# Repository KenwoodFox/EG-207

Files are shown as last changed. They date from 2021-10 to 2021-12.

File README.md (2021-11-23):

EG-207
======








Feel free to fork or create your own PRs! Join us on our [discord](https://discord.gg/vbgyRJBJCs)!

## Getting started building this code

More to come <3

### Tag Naming Scheme

Assignments should stay off this repo.  
Labs should use tags like so:  
`L<lab number>-RC<revision>`  
Labs should also not use subrevisions, and should rely on their `describe` functions to count appendex commits.

The final project should use:
`CMS-0.0`  
or  
`CMS-0.0RC0`

For example:
```
L1-RC1
L1-RC2
L1-RC3
```

And for final project
```
CMS-0.1RC1
CMS-0.1
CMS-0.2
CMS-0.3
CMS-0.4RC1
CMS-0.4RC2
```

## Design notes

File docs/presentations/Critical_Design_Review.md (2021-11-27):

---
title:
 - Team Gold Critical Design Review
subtitle:
 - Version &hash
author:
 - Joe
 - Maria
 - Noah
 - Josh
 - William
institute:
 - SNHU/CETA, EG-207
titlegraphic: resources/SNHU-CETA.png
theme: Ilmenau
navigation: frame
date: "Build Date: &date"
aspectratio: 1610
logo: resources/logo.png
fontsize: 8pt
section-titles: false
toc: false
---

# Introduction

## CDR Agenda

 - Concept of Operations (ConOps) Summary
 - Environmental Systems Description
 - Environmental Sensors
 - Requirement Compliance
 - Front Panel Display, Base-plate and Housing Design Details
 - Summary of Analyses
 - Calibration Plan
 - References/Citations
 - Next Steps

## Concept of Operations (ConOps) Summary

 - Stakeholders
   - We hold some stake in our own system.
   - The completion of our lab is important to those grading it.
 - Users
   - Scientists and Analysts in the field.
 - Operational Description
   - The sensor should be operated indoors and may be left without supervision to collect data and store it.
 - Support Environment
   - Released under the [GNUv3](https://www.gnu.org/licenses/gpl-3.0.en.html) license after final graded release `CMS-1.0-RELEASE` is published, and supported as the license describes, extending absolutely no warranty, and making all source code fully open source.

## Concept of Operations (ConOps) Summary Cont.

 - Use
   - The operator/analyst will use the sensor in the field, and collect data supervised or not.
 - Calibration
   - Calibration data is stored in the EEPROM and the sensor will not require calibration between regular uses, the sensor is not expected to require calibration often but will have a procedure to do so.
 - Impact consideration
   - Because our environmental monitoring solution does not have the same level of quality assurance as a similar solution, over-reliance by the end user could result in uncalibrated data, unexpected failure modes or strange untested bugs over time.
 - Risks
   - Increased risk of the system to malfunction if operation of system is prolonged without proper maintenance.
   - Potential light scatter non-visible to the naked eye.
   - Airborne contaminants can cause the system to malfunction and provide inaccurate data.

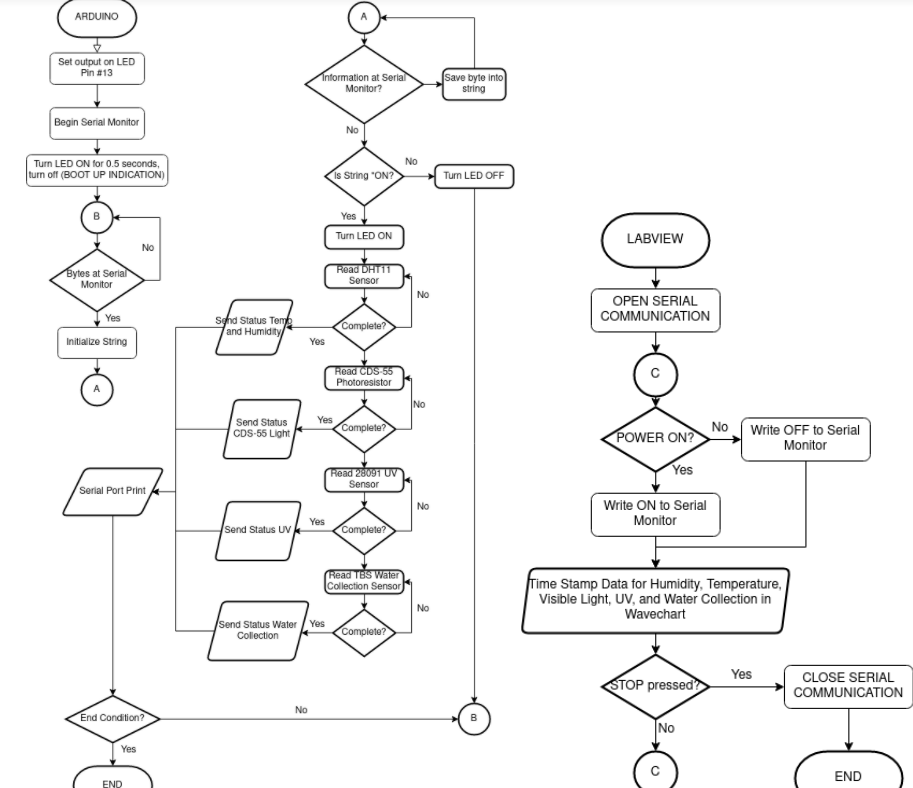
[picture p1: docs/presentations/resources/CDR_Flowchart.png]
Flowchart


## Environmental System Description

::: columns

:::: column

### Functional Block Diagram

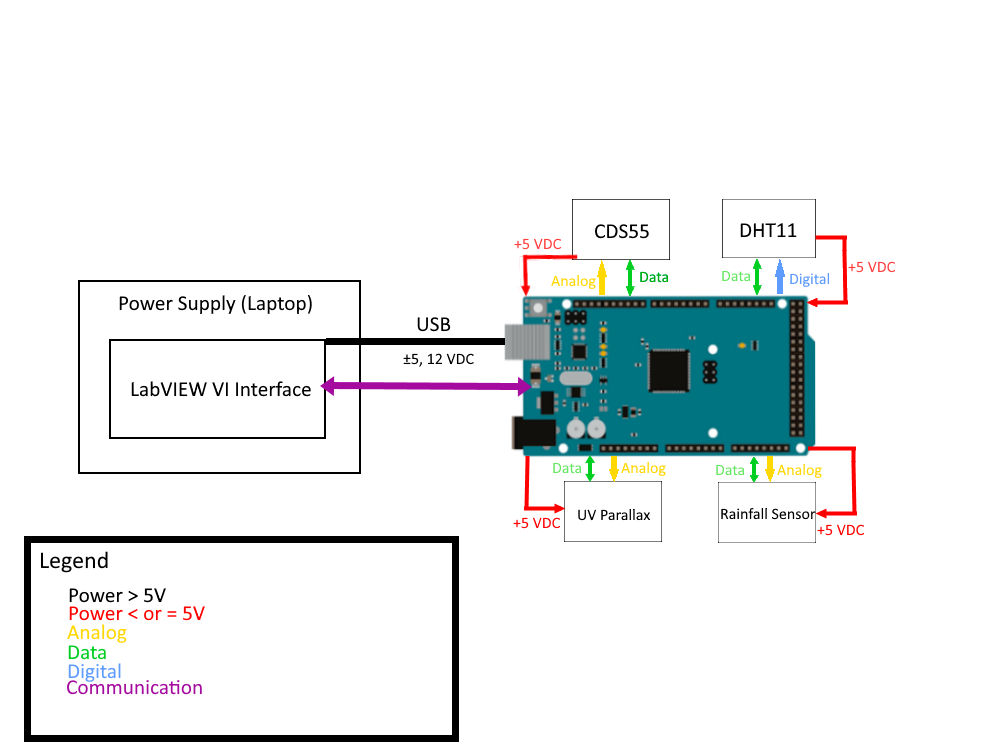
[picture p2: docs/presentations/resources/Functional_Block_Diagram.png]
Functional Block Diagram


::::

:::: column

- Instrument: LabVIEW 2019 SP1
- Data Acquisition: Arduino Mega 2560
- DAC Software: Arduino IDE 1.8.15
- Sensors:
  - Temp/RH: DHT11 Sensor
  - Visible Light: CDS55 Photoresistor
  - UV Light: 28091 UV Parallax Sensor
  - Water Collection: DGZZI Water Level Sensor Module

::::

:::

::: notes

This page needs some more work.

:::

## Environmental Sensors & Interfaces

::: columns

:::: {.column width=25%}

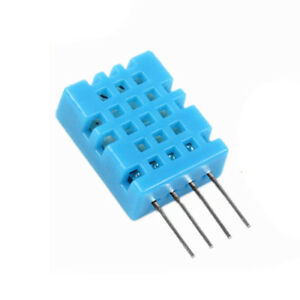
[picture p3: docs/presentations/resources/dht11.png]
DHT 11


The DHT 11 is an inexpensive  
serial type thermometer and  
hydrometer (John).

 - Humidity
   - Accuracy: ±5% RH
   - Precision: ±2% 
   - Response Time: 30 seconds

 - Temperature
   - Accuracy: ±2.5%
   - Precision: 2 Degrees Celcius 
   - Response Time: 30 seconds

::::

:::: {.column width=25%}

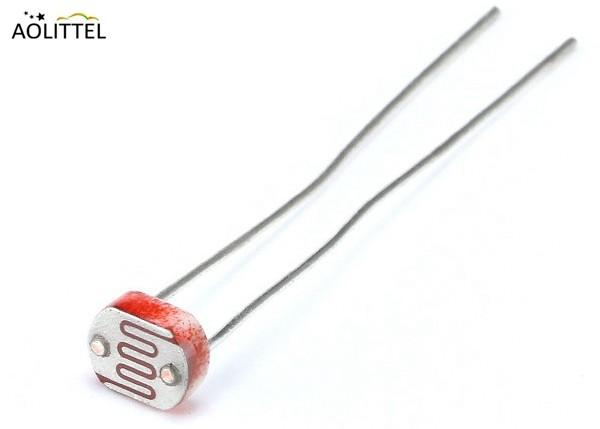
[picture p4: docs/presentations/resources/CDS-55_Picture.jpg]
CDS 55 Photoresistor


The CDS 55 is a commonly used  
visible light detecting photoresistor (KlSelectronic).

   - Accuracy: 10%
   - Precision: 20 lux 
   - Response Time: 0.30 seconds

::::

:::: {.column width=25%}

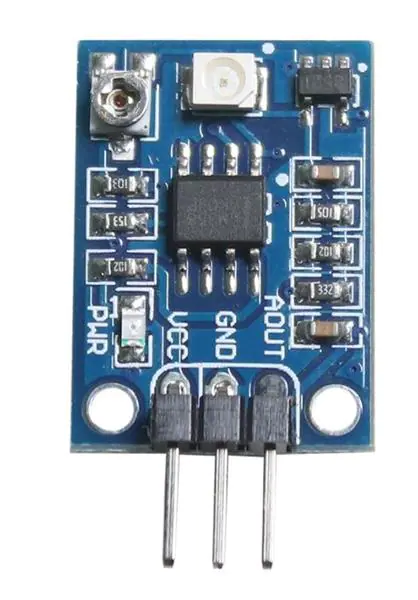
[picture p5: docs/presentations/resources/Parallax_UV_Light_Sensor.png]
Parallax UV Light Sensor


The parallax UV Sensor Breakout  
board is a breakout board  
used in prototypes  
to sense UV Light ("UV Light Sensor").

   - Accuracy: N/A
   - Precision: N/A 
   - Response Time: N/A

::::

:::: {.column width=25%}

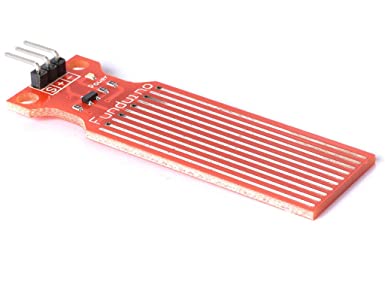
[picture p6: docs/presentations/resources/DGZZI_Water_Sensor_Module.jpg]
Water Level Sensor


The Water Level Sensor is used to 
measure the depths of water and the 
core component in an amplifying circuit.
The brick-designed sensor has three major
components: electronic brick connector,
1Mohm resistor, and several lines of
bare-conducting wires ("Last Minute Engineers"). 

   - Accuracy: ±1 mm
   - Precision: 0.2 mm 
   - Response Time: TBD

::::

:::

::: notes

This page needs some more work.

:::

# Requirements

## Functional Requirements - Compliance

| Reqt | Reqt Title | Statement Subject | Reqt Value | Perf.  | Margin | Notes/Basis |
|---|---|---|---|---|---|---|
| 3.1.1 | VI Front Panel | | | Comply | | |
| 3.1.1.1 | Sensor Read and Indications  | Numeric Indicators, "Warning" and "Alarm" LEDs | Provide for all sensors | Comply | N/A | Physical Indicators as well. |
| 3.1.1.2 | Senors Controls | Provide necessary controls | Arduino Power and STOP  | Comply | N/A | |
| 3.1.1.3 | Operation Indications | Display current system configuration and operating mode | LEDs for Indication | Comply | N/A | Physical Indicators as well. |
| 3.1.1.4 | Calibration Updates | Update Calibration Parameters through LabVIEW | | Comply | | |
| 3.1.2 | Update/Read Rate | | | | | |
| 3.1.3 | Warning and Alarm Indication | Provide warning or alarm indication for each sensor | | | | |

## Functional Requirements - Compliance Cont.

| Reqt | Reqt Title | Statement Subject | Reqt Value | Perf.  | Margin | Notes/Basis |
|---|---|---|---|---|---|---|
| 3.1.3.1 | Temperature (°F)  | Provide temperature warning or alarm indication | 85<T<100, > 100 | Comply | ±2^-1^ | |
| 3.1.3.2 | Humidity | Provide humidity warning or alarm indication | 30%<RH<40%, < 30% | Comply | | |
| 3.1.3.3 | Visible Light(lux)| Provide lux warning or alarm indication | 700<lux<1000, > 1000  | Comply | | |
| 3.1.3.4 | UV Light | Provide UV intensity warning or alarm indication | 300<U<600, > 600 | Comply | | |
| 3.1.3.5 | Water Level (mm)  | Provide rainfall warning or alarm indication | W<0.5 or 6<W<10, > 10 | Comply | | |
| 3.1.4 | Waveform Display  | Display waveform for sensors | Demonstrate | Comply | | |
| 3.1.5 | Data Logging | Time-stamped data exported to file with specific filename | Demonstrate, Inspect  | Comply | | On-Microcontroller Timestamp (to negate serial delay) |
| 3.1.6 | Operational Mode  | Provide additional mode | Demonstrate | Comply | | |

## Performance Requirements - Compliance

| Reqt. ID or section | Reqt. Title | Statement Subject | Reqt. Value | Perf. | Margin | Notes/Basis |
|---|---|---|---|---|---|---|
| 3.2.1 | Accuracy | Accuracy better than; | --- | | | |
| --- | --- | Temperature | ± 2.5ºC | ± 1.35ºC| 46.00% | |
| --- | --- | Humidity | ± 7% | ± 5.84% | 16.57% | |
| --- | --- | Vis Illuminance | ± 10% | ± 8.21% | 17.90% | |
| --- | --- | UV Intensity | N/A | N/A | N/A | N/A |
| --- | --- | Range detection | ± 1 mm | TBD | TBD | TBD |
| 3.2.2 | Precision | Precision better than; | --- | | | |
| --- | --- | Temperature | 2ºC | 1.23ºC  | 38.50% | |
| --- | --- | Humidity | 2% | 2.69% | -34.50%| |
| --- | --- | Vis Illuminance | 20 Lux | 2.69 | 86.55% | |
| --- | --- | UV intensity | N/A | N/A | N/A | N/A |
| --- | --- | Range detection | 0.2 mm | TBD | TBD | TBD |
| 3.2.3 | Calibration or Diagnostics | The display Shall provide ability to update calribration | Update via numerical Controls | Comply  | | |

# Prototypes

## Front Panel Display Design (LabVIEW)

::: columns

:::: {.column width=60%}

### LabView Front Panel

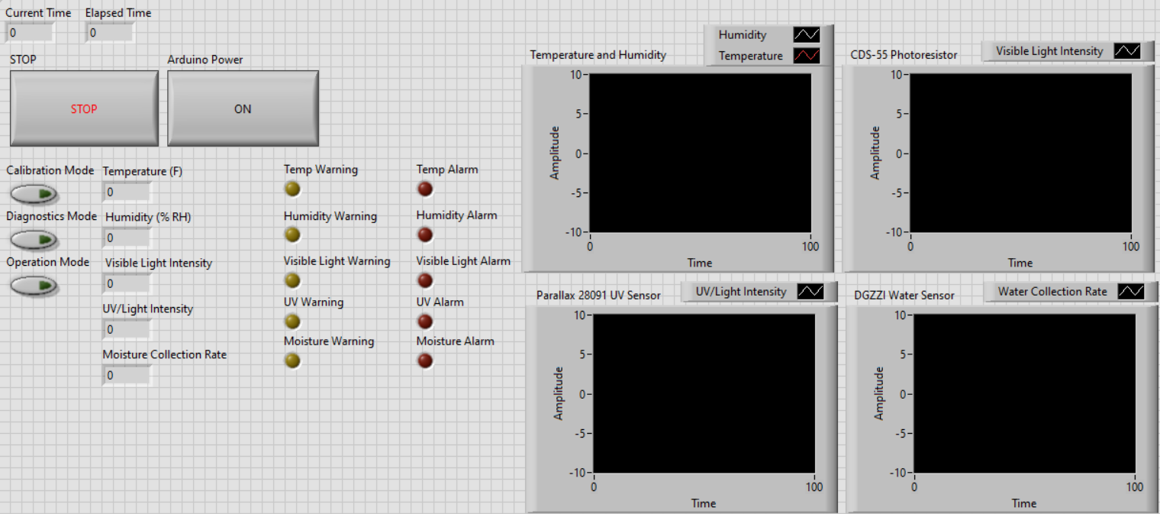
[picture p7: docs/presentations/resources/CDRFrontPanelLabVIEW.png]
Team Gold LabView Front Panel


::::

:::: column

- Environmental Varaiables
  - Temperature
  - Humidity
  - Visible Light Intensity
  - UV/Light Intesnsity
  - Moisture Collection Rate

- Control Functions
  - On & Off switch for LabVIEW
  - Calibration Mode
  - Diagnostics Mode
  - Operation Mode

- Sensor Warning Lights
  - Temperature Warning light
  - Humidity Warning light
  - Visible Light Warning light
  - UV/Light Warning light
  - Moisture Warning light

- Sensor Alarm Light 
  - Temperature Alarm light
  - Humidity Alarm light
  - Visible Light Alarm light
  - UV/Light Alarm light
  - Moisture Alarm light

::::

:::

::: notes

This page needs some more work.

:::

## Sensor Package Assembly Model

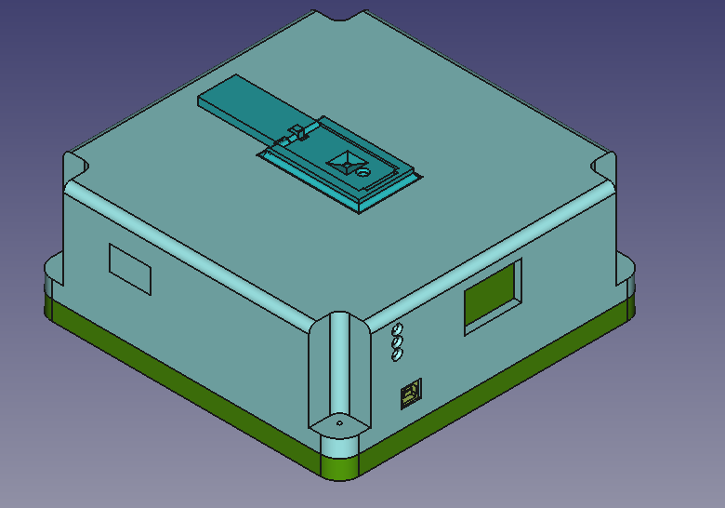
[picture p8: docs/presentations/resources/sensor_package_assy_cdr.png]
Team Gold Sensor Package Assembly Model


::: notes

This page needs some more work.

:::

## Base plate Design Drawing

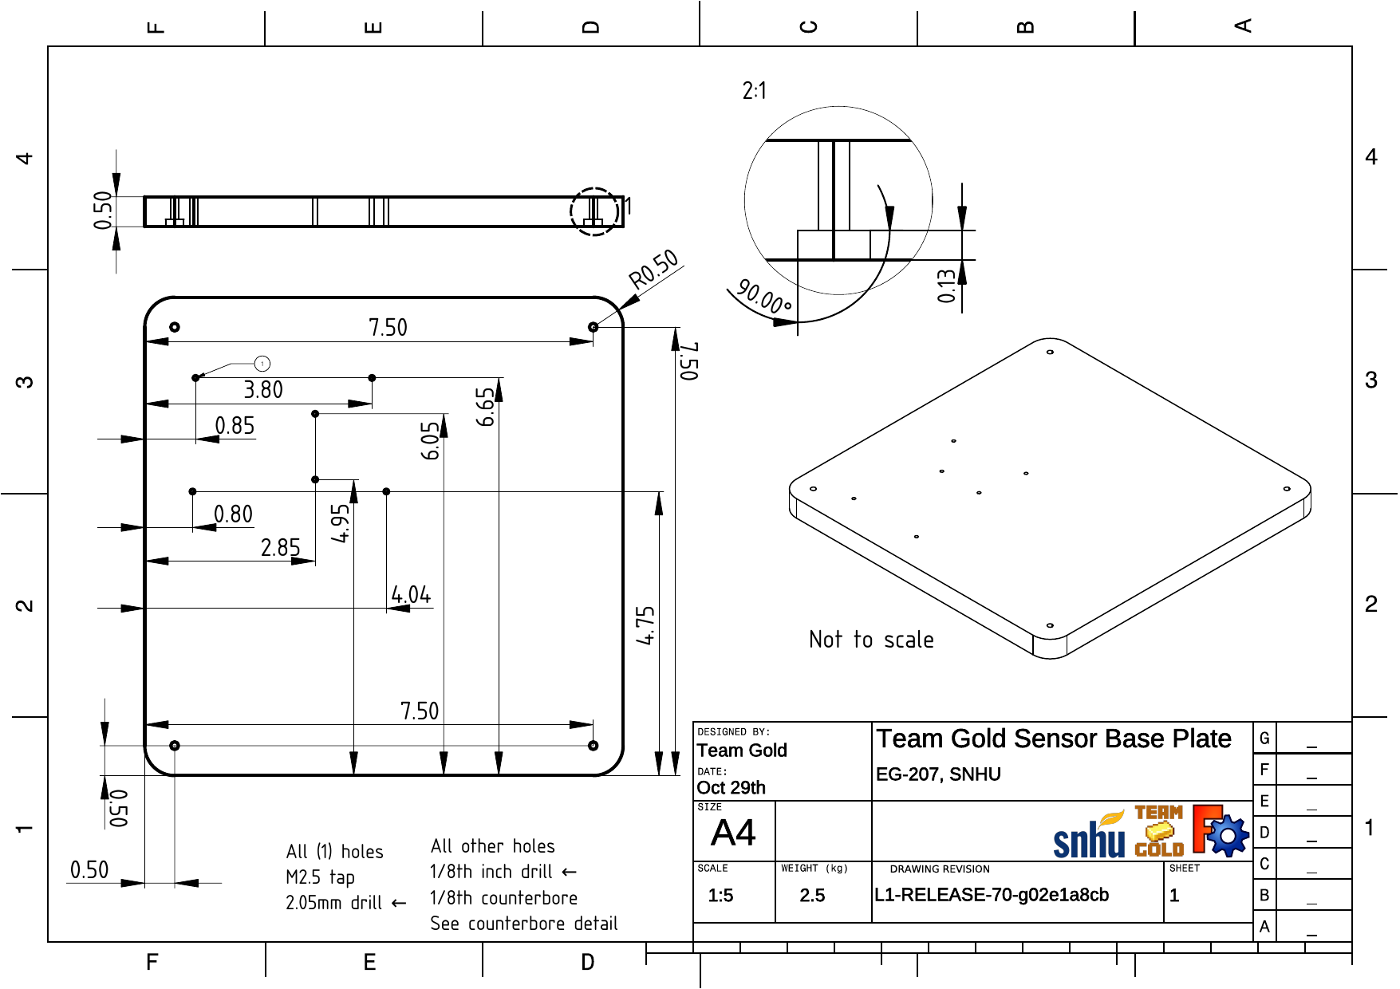
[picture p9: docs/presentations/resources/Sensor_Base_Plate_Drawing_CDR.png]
Team Gold Base Plate Design


::: notes

This page needs some more work.

:::

## Housing Design - Solid Model

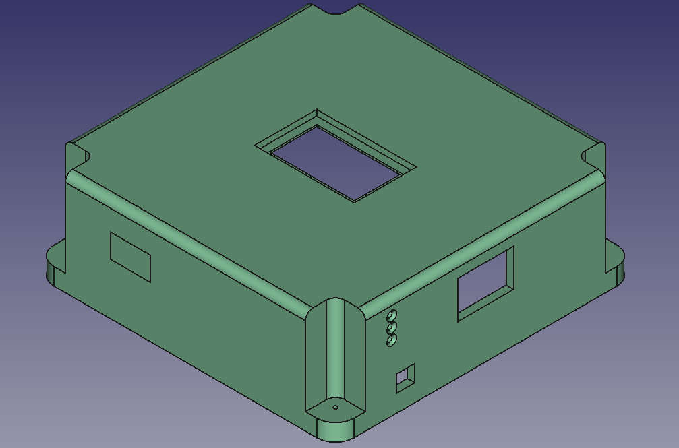
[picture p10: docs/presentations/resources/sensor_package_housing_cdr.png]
Team Gold Solid Model


::: notes

Have some callouts and stuff for  
important features and cutouts on model.

:::

## Housing Design - Drawing

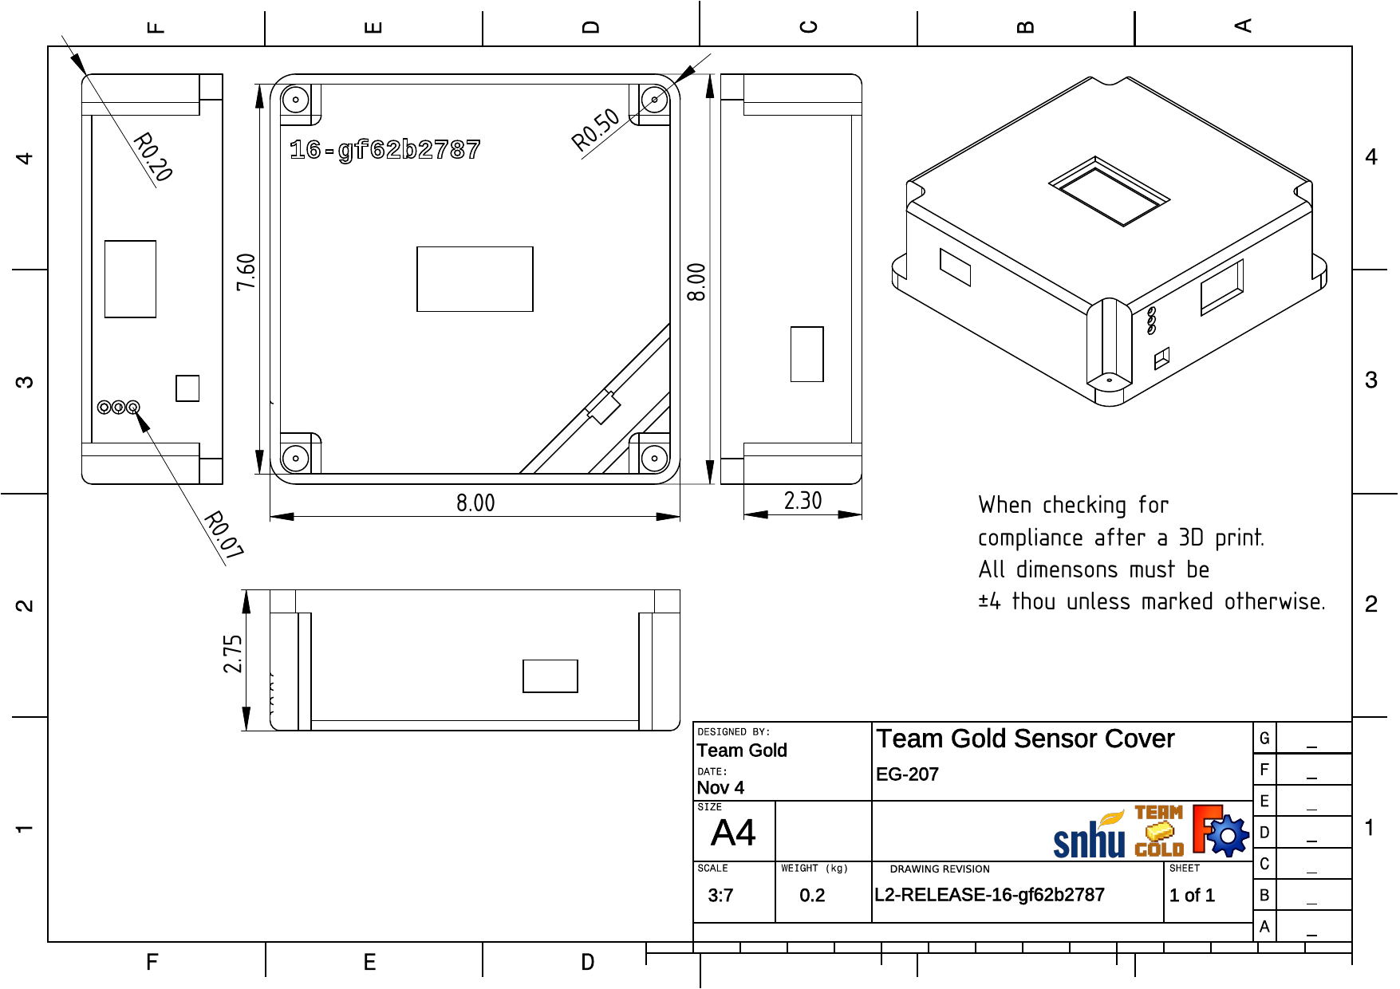
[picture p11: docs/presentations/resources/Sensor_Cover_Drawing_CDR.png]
Team Gold Housing Design Drawing


::: notes

Just put the drawing here

:::

# Analyses

## List and Summary of Analyses

::: The calculated accuracy and precision measurements were found together as a team
using Joe's data of the Visible Light and UV Sensor from the Arduino code, and Noah's data
of the humidity and temperature they provided as it represented the best values to calculate
the margin.

This page needs some more work.

:::

## Calibration Plan

::: columns

:::: column

### Auto-Calibration

Procedure for undergoing an autocal:

 - When sensor is first powered on, these conditions must be met:
   - Light Sensor door must be closed.
   - Neither Sensor must read an absolute 0 value.
   - There must be no error codes in the error EEPROM location.
   - There must be no warning, or out-of-range codes in the warning EEPROM location.
 - If all conditions are met, the sensor will compare its previous 0 mark to the current readings of the light sensors
   - If they differ:
     - Sensor will average 10 seconds of recording and create a new offset, and store this in the EEPROM
     - Sensor will then allow a user to extend or retract the light sensor door as normal, while also raising a warning code for 50 seconds indicating it has had a recent autocal.
   - If they do not differ:
     - Sensor will not change the value and will not wait 10 seconds or raise a warning code.

::::

:::: column

### Manual Calibration

Neither the water sensor, nor the DHT11 can have an accurate autocal routine, these sensors must be calibrated by the operator via the LabVIEW vi.

 - To calibrate the DHT11
   - The sensor must start in or be in this state:
     - Light Sensor Door closed.
     - No error codes.
     - No out-of-range or warning codes.
   - The operator must specify their own offset values via the VI, and submit them to the sensor with a AUTOCAL tagged packet
   - The sensor will store these offsets in its EEPROM
 - To Calbrate the Water Flow Sensor
   - The operator must meet the state defined for the DHT11 Calibration
   - They can input their own values, or alternativly, select the 'zero' button for the flow sensor, to calibrate in a known dry enviorment.

::::

:::

::: notes

This page needs some more work.

:::

# Appendix

## References/Citations

“C:UsersAdministratorDesktop~$KLS6-3537 - Klsele.com.” KlSelectronic. Accessed October 22, 2021. 
	http://www.klsele.com/admin/product_upload/20190322144057KLS6-3537..pdf. 

“UV Light Sensor.” UV Light Sensor | 28091 | Parallax Inc. Accessed October 22, 2021. 
	https://www1.parallax.com/product/28091. 

John G. Webster, & Halit Eren. (2014). Measurement, Instrumentation, and Sensors Handbook: Two-Volume Set. CRC Press. 

Last Minute Engineers. “In-Depth: How Water Level Sensor Works and Interface It with Arduino.” Last Minute Engineers. 
	Last Minute Engineers, December 18, 2020. 
	https://lastminuteengineers.com/water-level-sensor-arduino-tutorial/. 

:::

## Next Steps

 - Fabrication of Baseplate
 - Complete manufactoring of rain bucket
 - Finalize Arduino Code 
 - Construct LabVIEW for all sensors and their environments
 - Configure the wiring from Arduino to the bread board for all sensors

# Extra Material

## Team Members

::: columns

:::: {.column width=20%}

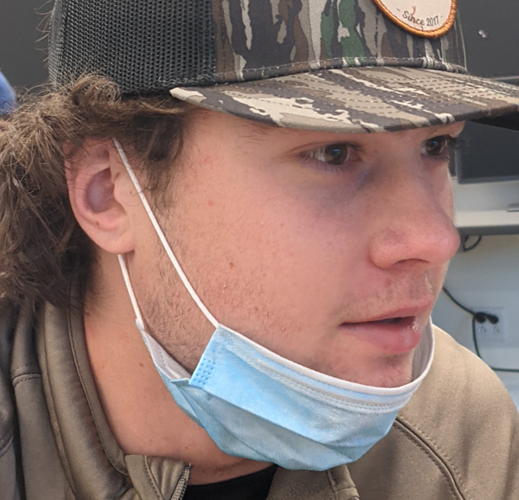
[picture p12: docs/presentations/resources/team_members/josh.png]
  
Josh

::::

:::: {.column width=20%}

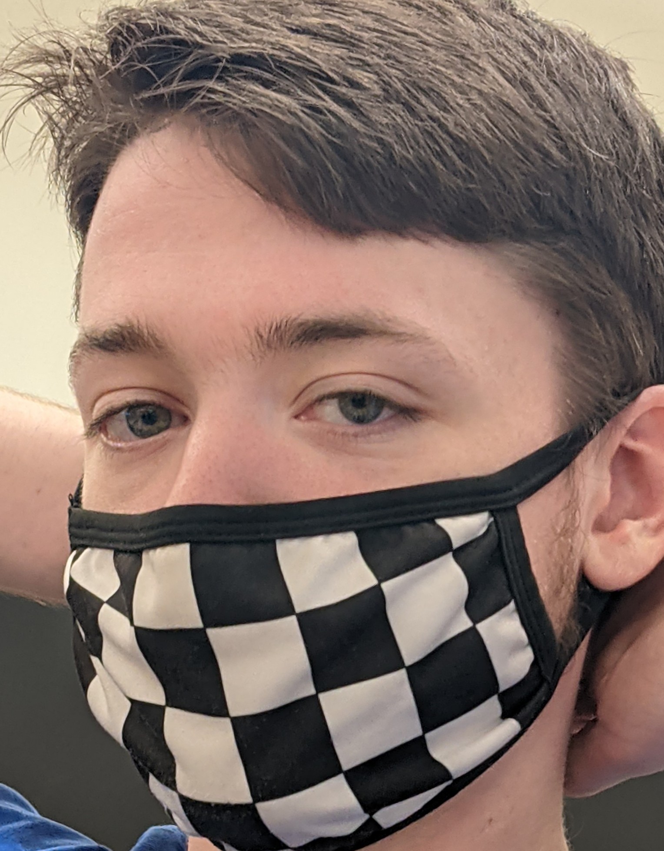
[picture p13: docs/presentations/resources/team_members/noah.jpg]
  
Noah

::::

:::: {.column width=20%}

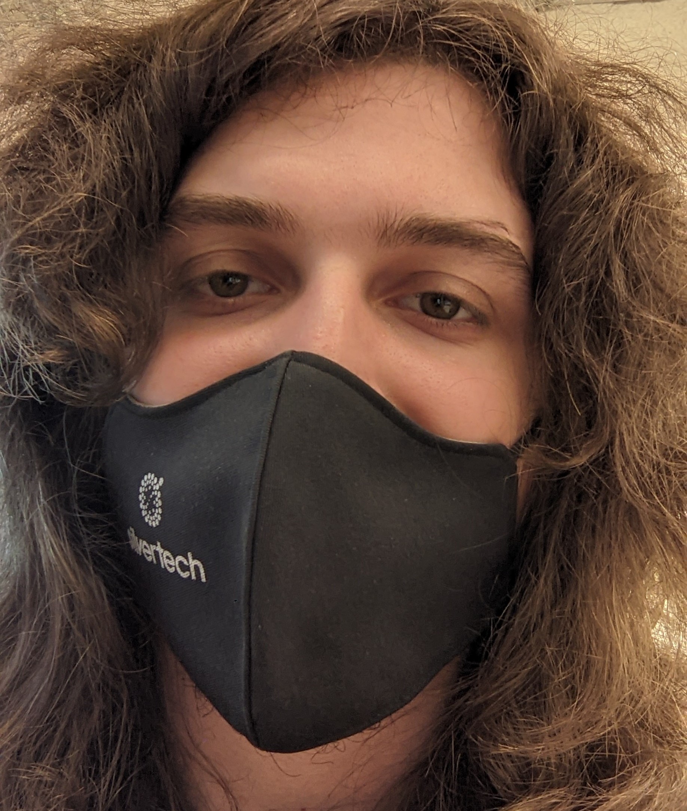
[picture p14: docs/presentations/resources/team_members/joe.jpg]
  
Joe

::::

:::: {.column width=20%}

  
Maria

::::

:::: {.column width=20%}

  
Will

::::

:::

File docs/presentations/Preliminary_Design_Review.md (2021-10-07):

---
title:
 - Team Gold Preliminary Design Review
subtitle:
 - Version &hash
author:
 - Joe
 - Maria
 - Noah
 - Josh
 - William
institute:
 - SNHU/CETA, EG-207
titlegraphic: resources/SNHU-CETA.png
theme: Madrid
navigation: frame
date: "Build Date: &date"
aspectratio: 1610
logo: resources/logo.png
fontsize: 8pt
---

# PDR Agenda

 - Con-Ops Summary
 - Environmental System Description
 - Environmental Sensors
 - Performance Requirements/Compliance
  - Functional
  - Performance
  - Verification
 - Base-plate/Housing Design Concepts
 - Next Steps

# Concept of Operations (Con-Ops) Summary

 - Stakeholders
   - We hold some stake in our own system.
   - The completion of our lab is important to those grading it.
 - Users
   - Scientists and Analysts in the field.
 - Operational Description
   - The sensor should be operated indoors and may be left without supervision to collect data and store it.
 - Support Environment
   - Released under the GNUv3 license after final graded release `CMS-1.0-RELEASE` is published, and supported as the license describes, extending absolutely no warranty.
 - Use
   - The operator/analyst will use the sensor in the field, and collect data supervised or not.
 - Calibration
   - Calibration data is stored in the EEPROM and the sensor will not require calibration between regular uses, the sensor is not expected to require calibration often but will have a procedure to do so.

# Concept of Operations (Con-Ops) Summary Cont.

 - Impact consideration
   - Because our environmental monitoring solution does not have the same level of quality assurance as a similar solution, over-reliance by the end user could result in uncalibrated data, unexpected failure modes or strange untested bugs over time.
 - Risks
   - Increased risk of the system to malfunction if operation of system is prolonged without proper maintenance.
   - Airborne contaminants can cause the system to malfunction and provide inaccurate data.

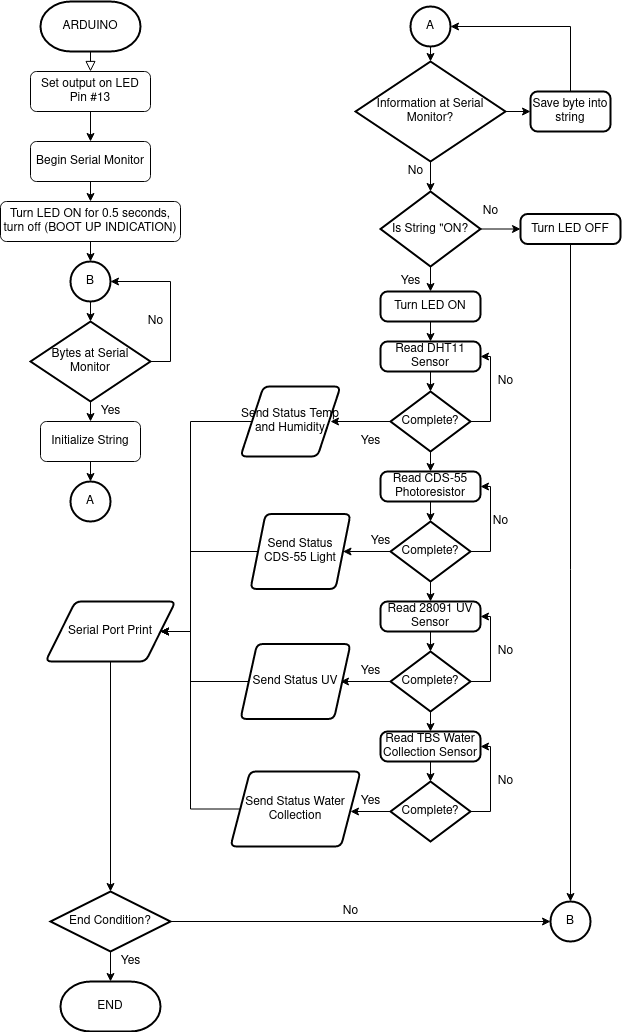
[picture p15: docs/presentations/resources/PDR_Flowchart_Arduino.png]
Con Ops Flow Chart (Arduino)
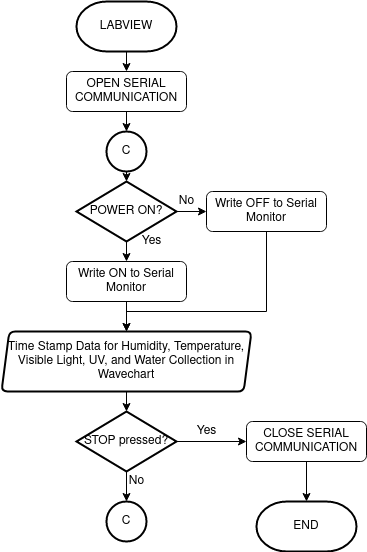
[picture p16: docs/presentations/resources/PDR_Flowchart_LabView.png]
Con Ops Flow Chart (LabView)
 

# Environmental System Description

 - Instrument: LabVIEWw 2019
 - Data Acquisition: Arduino AVR (mega)
 - DAC Software: Arduino + pyplot and numpy
 - Sensors:
   - Temp/RH: DHT11
   - UV Light: TBD
   - Visible Light: Photo-resistor

# Environmental Sensors

 - Sensors:
   - Temp/RH: DHT-11
   - Visible Light: CDS-55
   - UV Light: Parallax 28091

DHT 11 Sensor
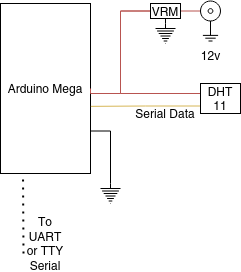
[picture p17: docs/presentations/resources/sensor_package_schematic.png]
Sensor Package Schematic


# Performance Requirements - Compliance

| Reqt  | Owner | Title | Reqt Value | Perf. | Margin | Notes/Bias |
|---|---|---|---|---|---|---|
| 3.1.1 | Team Gold | Virtual Instruments Front Panel | Demonstrate, Inspect | Complies | | |
| 3.1.2 | Team Gold | Sensor Update/Read Rate | Demonstrate, Inspect | Interrupt Based | ISR | |
| 3.1.3 | Team Gold | Warning and Alarm Indication | Demonstrate, Test | Complies | | Sensor yellow and red limits and decision-making flow chart req’d |
| 3.1.4 | Team Gold | Waveform Display | Demonstrate | Complies | | |
| 3.1.5 | Team Gold | Data Logging | Demonstrate, Inspect | Complies | | Data file to be provided in ADP |
| 3.1.6 | Team Gold | Operational Modes | Demonstrate | Complies | | |
| 3.2.1 | Team Gold | Sensor Accuracy | Validation | Characterized | | Standard to be used for accuracy determination |
| 3.2.2 | Team Gold | Sensor Precision | Analysis, Validation | Characterized | | Standard deviation analysis req’d |
| 3.2.3 | Team Gold | Calibration or Diagnostics | Demonstration | Built in | | |

# Performance Requirements - Compliance Cont.

| Reqt | Owner | Title | Reqt Value | Perf. | Margin | Notes/Bias |
|---|---|---|---|---|---|---|
| 3.3.1 | Team Gold | Mounting | Analysis, Demonstration | Complies | | |
| 3.3.1.1 | Team Gold | Base-plate Bottom Surface | Demonstration | Complies | Flush | |
| 3.3.1.2 | Team Gold | Housing to Base-plate | Demonstration | Complies | Flush | |
| 3.3.2 | Team Gold | Electrical | Validation, Demonstration | Complies | Proto | System Electrical Circuit Diagram req’d (including Arduino functions) |
| 3.3.3 | Team Gold | Data Power and Access | Demonstration | Complies | TTY | |
| 3.4.1 | Team Gold | Housing | Validation, Demonstration | Complies | | *STL file and outline drawing required for fabrication |
| 3.4.2 | Team Gold | Base-plate | Validation | Complies | | |
| 3.4.3 | Team Gold | Electrical | Validation | Complies | | |
| 3.4.4 | Team Gold | Hardware | Validation, Inspection | Complies | Collected | |
| 3.5.1 | Team Gold | Team Structure | Demonstration | Does Not Comply | | |

# Performance Requirements - Compliance Cont.

| Reqt | Owner | Title | Reqt Value | Perf. | Margin | Notes/Bias |
|---|---|---|---|---|---|---|
| 3.5.2 | Team Gold | Team Communications | Demonstration, Inspection | Complies[^1] | | Weekly email status reports |
| 3.5.3 | Team Gold | PDR and CDR Presentations | Demonstration | Complies | Automatic | Presentation templates provided, reviewed class before presentations |
| 3.5.4.1 | Team Gold | System Fabrication | Demonstration, Inspection | Complies | | Base-plate part file/fab drawing and cover STL file/outline drawing  |
| 3.5.4.2 | Team Gold | System Demonstration | Demonstration | Complies | | Instructor executes final verification activity |
| 3.5.5 | Team Gold | System ADP | Inspection | Complies | | ZIP file of all native files |

[^1]: See our [discord](https://discord.gg/gQ547MBvgA).

# Verification Requirements

| Reqt  | Title | Method | Notes/Bias |
|---|---|---|---|
| 3.1 | Functional Requirements | | |
| 3.1.1 | Virtual Instrument panel | D[^D], I[^I] | By including it we can demonstrate that we meet this req. |
| 3.1.2 | Sensor Update/Read Rate | A[^A], D | We will use interrupt based frame handling, to avoid 'read rate' issues. |
| 3.1.3 | Warning and Alarm Indication | D, T[^T] | Sensor and red limits and decision-making flow chart |
| 3.1.4 | Waveform Display | D | |
| 3.1.5 | Data Logging | D, I | Data file to be provided in ADP |
| 3.1.6 | Operational Modes | D | The sensor will operate as a state machine, and have transition states |
| 3.2 | Performance Requirements | | |
| 3.2.1 | Sensor accuracy | V[^V] | Standard to be used for accuracy determination |
| 3.2.2 | Sensor Precision | A, V | Standard Deviation Analysis |
| 3.2.3 | Calibration Diagnostics | D | |
| 3.3 | Interface Requirements | | |
| 3.3.1 | Mounting | A, D | |

[^D]: Demonstrate.
[^I]: Inspection.
[^T]: Test.
[^V]: Validation.
[^A]: Analysis.

# Verification Requirements Cont.

| Reqt | Title | Method  | Notes/Bias |
|---|---|---|---|
| 3.3.1.1 | Base-plate Bottom Surface | D[^D] | Flush mount only! |
| 3.3.1.2 | Housing to Base-plate | D | Screws on mounting corners. |
| 3.3.2 | Electrical | V[^V],D | System Electrical Circuit Diagram |
| 3.3.3 | Data and power Access | D | Utilizing only VRM power (if no more is required) |
| 3.4 | Design Requirements | | |
| 3.4 1 | Housing | V,D | STl file anf outline drawing required for fabrication |
| 3.4.2 | Base-plate | V | Modeled in 3D, manufactured to 2D spec. |
| 3.4.3 | Electrical | V | Solder and protoboarding |
| 3.4.4.  | Hardware | V,I[^I] | |
| 3.5 | Project Requirements | | |
| 3.5.1 | Team Structure | D | Unstructured, plans to implement a team leader? |
| 3.5.2 | Team Communications | D,I | Weekly email status reports |
| 3.5.3 | PDR and CDR Presentations | D | Presentation templates provided, reviewed class before presentations |
| 3.5.4 | System Fabrication | D,I | Base-plate part file/fab/ drawing and cover STL file/outline drawing |
| 3.5.4 | System Demonstration | D | Instructor executes final verification activity |
| 3.5.5 | System ADP | I | ZIP file of all native files |

# Concepts/RC0

## Base Plate

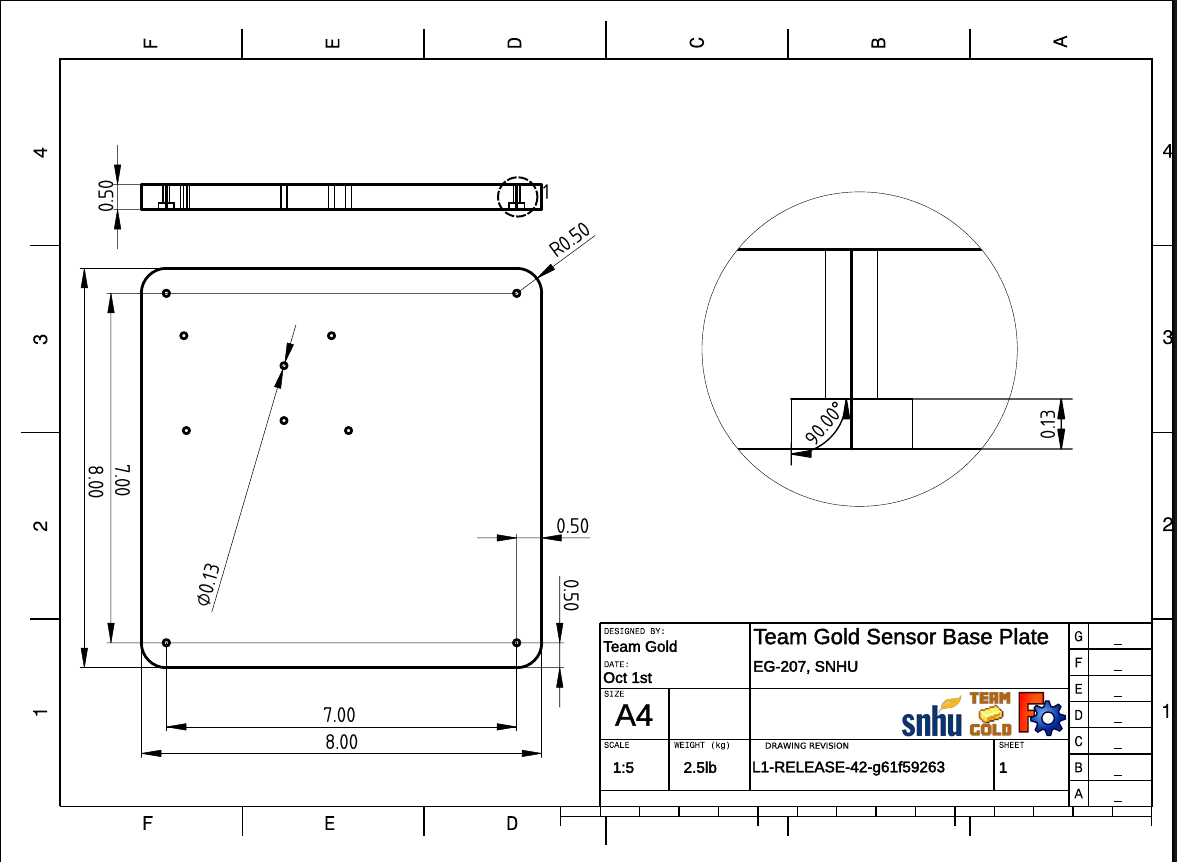
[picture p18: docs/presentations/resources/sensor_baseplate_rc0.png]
Base-plate Drawing


The base plate is ready to machine and has its drawings written up.

# Concepts/RC0 Cont.

## Shell

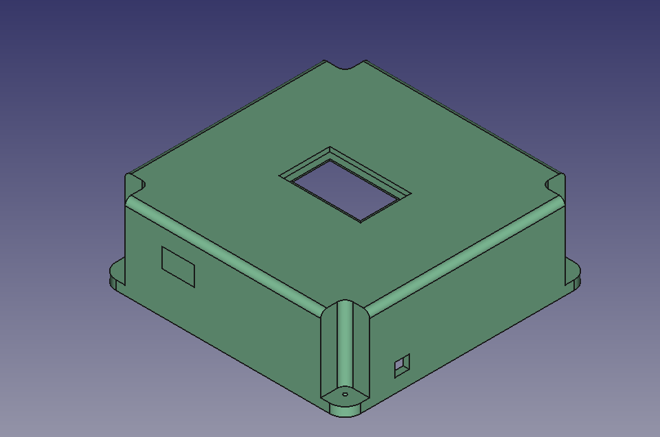
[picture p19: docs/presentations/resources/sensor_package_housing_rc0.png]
Shell 3D Render


The Upper shell contains all the mounting for each sensor save for the light sensor, witch has its own, actuated housing.

# Concepts/RC0 Cont.

## LabView

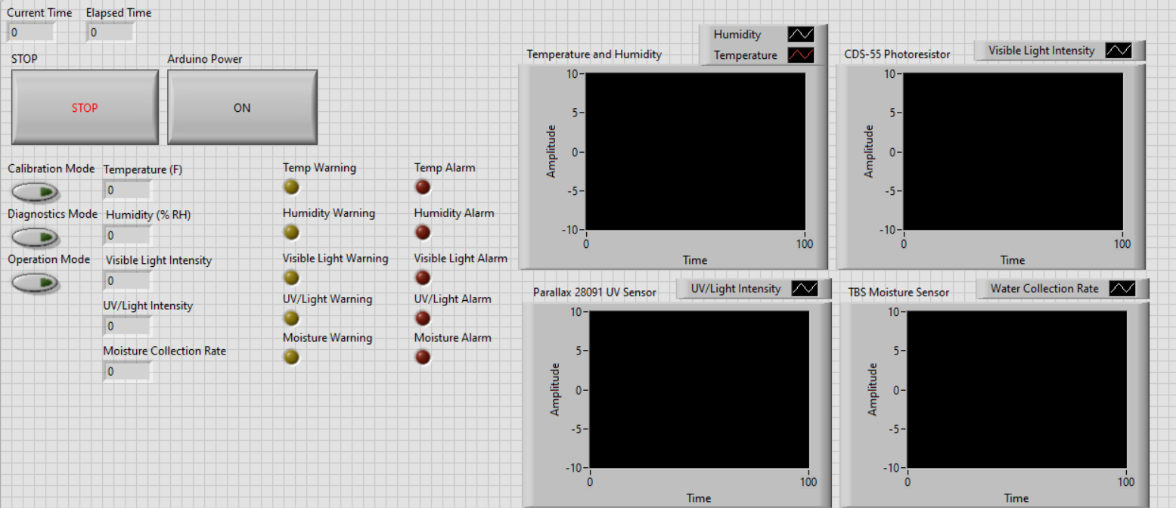
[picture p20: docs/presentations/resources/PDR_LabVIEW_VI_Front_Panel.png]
Lab View VI prototype


# Concepts/RC0 Cont.

## Custom frame-based communications standard

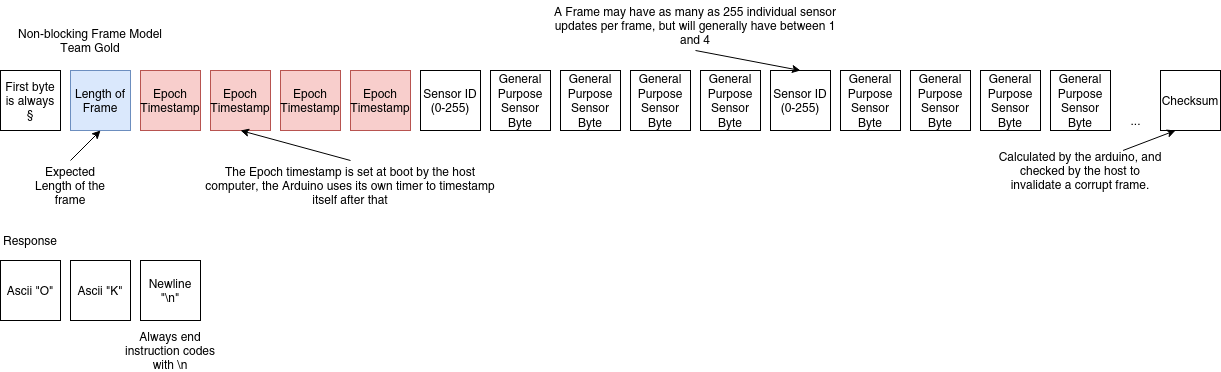
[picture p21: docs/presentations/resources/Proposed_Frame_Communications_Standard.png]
Custom Frame Standard


We propose creating our own, standard byte-by-byte frame based communication protocol to facilitate better resource management as well as cleaner code.

# Next Steps[^2]

 - Complete RC1 manufacturing on plastic cover
 - Complete prototyping of light sensor housing
 - Machine Base-plate
 - Construct/Finalize VI

[^2]: Next steps copied from kaban, see cards for latest status: [Link](https://github.com/KenwoodFox/EG-207-CCEMS/projects/1)

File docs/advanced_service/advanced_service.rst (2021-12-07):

Advanced Service
================

ProtoBoard Pins
###############

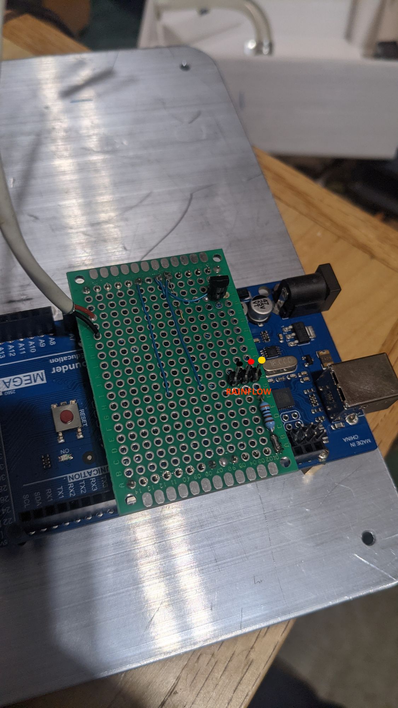
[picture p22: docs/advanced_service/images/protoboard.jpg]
Rainflow Service Cover


Dismantle the Light Sensor Door
###############################

.. note::
  You must remove your CMS's cover before continuining.

.. warning::
  Do not power CMS with lid removed!

Locate the clips on the bottom of the :ref:`Light Sensor Aperture`

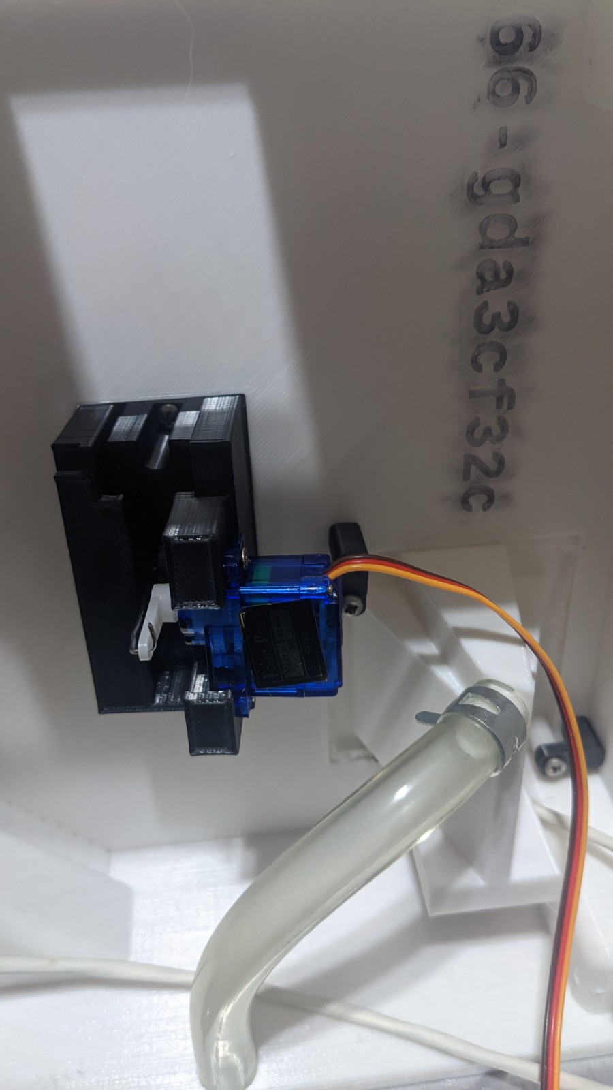
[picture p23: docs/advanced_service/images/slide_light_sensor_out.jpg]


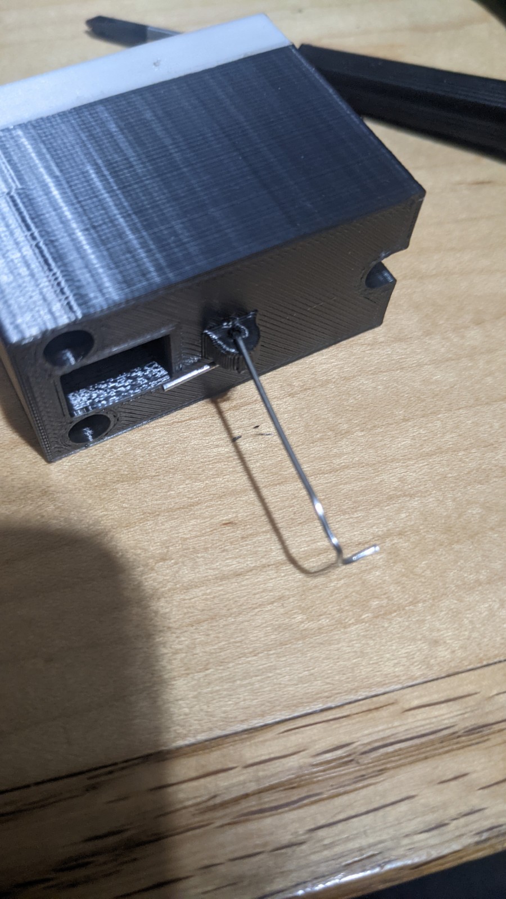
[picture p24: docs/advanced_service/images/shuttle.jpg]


NAMEME

NAMEME

NAMEME

NAMEME

NAMEME

NAMEME

NAMEME

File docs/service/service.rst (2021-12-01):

Service
=======

Some parts of your CMS are user serviceable, and may require service during normal
operation. The following chart details at what time parts may need to be serviced.

Service Schedule
################

.. list-table:: Service Schedule
   :widths: 50 25 25
   :header-rows: 1

   * - Service
     - Hours
     - Cycles
   * - Clean Light Aperature
     - 50hrs
     - N/A
   * - :ref:`Clean the Rain Flow Sensor`
     - 100hrs
     - N/A
   * - Lubricate Light Sensor
     - 150hrs
     - 600 cycles
   * - Replace Rain Flow Sensor
     - 1600hrs (or when failed)
     - N/A

Clean the Rain Flow Sensor
##########################
  
Refer to the :ref:`Service Schedule` to determine when the rain flow sensor should be inspected.

Follow the next steps to properly clean your Rain Flow Sensor.

Remove the rain sensor grate, make sure the grate is free of debris before reinstalling.

Rainflow Service Cover

.. note::

  If debris falls into the rain sensor, use a pair of tweezers to remove it. Be sure to confirm
  there are no debris before reinstalling the grate or other components.

Unscrew the two screws covering the circuitry of the Rain Flow Sensor.

Rainflow Service Cover

Next, Unplug and slide the water level sensor out.

Rainflow Water Level Sensor

Perform a visual inspection, check for debris, corrosion or other irregularities, if the sensor visually looks good, reinstall the sensor and screw the cover back on.

Acceptable Corrosion Level

.. warning::

    Rainflow Service Cover Gasket
  
  When reinstalling the service cover, be sure to not loose the small gasket found between the two parts.

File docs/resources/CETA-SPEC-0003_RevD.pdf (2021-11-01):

SNHU CETA SPECIFICATION | REVISION D
CETA-SPEC-0003

SNHU School of Engineering, Technology and Aeronautics (SETA) IDE Building, 2500 North River Rd.
Manchester, NH 03106

Page 1

# SPECIFICATION

# FOR THE

# Climate Change Environmental Monitoring System

### Prepared for:

### EG207 Instrumentation and Measurement Fall 2021

SNHU School of Engineering, Technology and Aeronautics (SETA) IDE Building, 2500 North River Rd.

Page 2

# REVISION LOG

Version/Release | Description | Date | Issuer
- | Initial Issue | 9/12/21 | PSD
A | Definition of baseplate geometry | 9/20/21 | PSD
B | Added Arduino MEGA 2560 Mounting Outline | 9/29/21 | PSD
C | Section 3.1.1 – Separate Requirements Section 3.1.3 – Added Warning and Alarm Limits in new Table 2 Section 3.4.2 – Specify standoff screw lengths Section 3.4.4 – Clarified requirement | 10/12/21 | PSD
D | Section 2.1 – Addition of Water Sensor datasheet reference Section 2.2 – Added CDR Template reference Section 3.1.1.4 – Added Calibration Updates via Front Display Section 3.1.3 – Clarification of Visible and UV Warning and Limits, addition of Water Level limits Sections 3.2.1,3.2.2 – Update Accuracy and Precision requirements Sections 3.4.1,3.4.2 – Separation into Individual Requirements Section 4.2, Table 5 – Updated per changes noted above | 10/30/21 | PSD

SNHU School of Engineering, Technology and Aeronautics (SETA) IDE Building, 2500 North River Rd.

Page 3

# TABLE OF CONTENTS

SNHU School of Engineering, Technology and Aeronautics (SETA) IDE Building, 2500 North River Rd.

Page 4

SNHU School of Engineering, Technology and Aeronautics (SETA) IDE Building, 2500 North River Rd.

Page 5

# LIST OF FIGURES

Figure 1. EG207 Fall 2021 Sensor System Layout | 6
Figure 2. Arduino MEGA 2560 Mounting Outline | 11

# LIST OF TABLES

Table 1. System Environmental Variables and Customer-Supplied Sensors | 6
Table 2. Sensor Warning and Alarm Limits | 9
Table 3. Sensor Accuracy Requirements | 10
Table 4. Sensor Precision Requirements | 10
Table 5. System Verification Compliance Matrix | 15


SNHU School of Engineering, Technology and Aeronautics (SETA) IDE Building, 2500 North River Rd.

Page 6

## 1 SCOPE

This document lists the technical, project and verification requirements for the Climate Change Environmental Monitoring System (hereby referred to as the “System”) for which a Prototype System is to be developed by the EG207 Fall 2021 class sections within the Southern New Hampshire Univerity (SNHU) School of Engineering, Technology and Aeronautics (SETA). SNHU-SETA will hereby be referred to as the “Customer”. The System will provide the means to continually monitor environmental conditions and record data in a data log. Sections 1 and 2 of this document list the scope and applicable documents/files to this project. Section 3 provides the technical and project requirements while Section 4 provides the verification requirements. The Customer has identified the methods of verification for some of the primary requirements as identified in Section 4. Each team may determine the methods of verification for the remaining requirements not addressed by the customer.

### 1.1 Introduction

The System will measure and monitor the following environmental variables using the customer-supplied environmental sensors shown in Table 1. The sensor datasheets are provided in Section 5.

Environmental Variable | Customer-Supplied Sensor
Temperature | DHT11 Humidity
Visible Light Illuminance | CDS-55 Photoresistor
UV Light Intensity | Parallax 28091
Water Collection | DGZZI Sensor Module
Table 1. System Environmental Variables and Customer-Supplied Sensors

The Customer will also provide an Arduino Uno or MEGA microcontroller board as part of an ELEGOO project kit and a licensed version of LabVIEW® 2019. Arduino software is open-source and free to use. Arduino software customized to the sensors provided as part of the ELEGOO kit is provided on the CD provided with that kit.

### 1.2 System Definition

The sensor package system layout is shown in Figure 1. A student-provided laptop running LabVIEW 2019 should provide a virtual instrument front panel which controls and reads from the sensor package.

Figure 1. EG207 Fall 2021 Sensor System Layout

SNHU School of Engineering, Technology and Aeronautics (SETA) IDE Building, 2500 North River Rd.

Page 7

### 1.3 Responsibilities

The Customer will provide the software, data acquisition and sensor hardware as identified in Section 1.1. The Project Team shall be responsible for the following;

1. Analysis and design of an environmental monitoring system using a LabVIEW® Virtual Instrument (VI) interface with the Arduino microcontroller/data acquisition board and a multiple sensor breadboard,
2. Analysis, design and fabrication of;
a. Prototype sensor housing or casing such that this component can be fabricated via 3-D printing, and
b. Prototype system baseplate machined in Aluminum 6061-T6
3. Assembly and test of the prototype environmental monitoring system,
4. Verification of the fully-integrated environmental monitoring system in accordance with the verification methods and details provided in Section 4, and
5. Execution of this project in accordance with the project requirements specified in Section 3.5.

SNHU School of Engineering, Technology and Aeronautics (SETA) IDE Building, 2500 North River Rd.

Page 8

## 2 APPLICABLE DOCUMENTS

The documents listed in this section are applicable to this specification. Document revisions and versions are not specified as the specific applicable document revision or version is the current revision or version in effect.

### 2.1 Customer Specifications and Files

The following customer specifications and files are applicable to this document.

Document No./Filename | Title
DHT-Technical-Data-Sheet.pdf | Datasheet – DHT11
CDS-55 Photoresistor.pdf | Datasheet – CDS-55
28091-UV-Sensor.pdf | Datasheet – Parallax 28091 UV Sensor
Water_Level_Sensor.pdf | Datasheet – Water Collection Module
| ELEGOO Arduino Mega 2650 CD (Files, Code, Libraries)

### 2.2 Project Documents

The following project documents are applicable to this.

Document No./Filename | Title
EG207_PDR_Template.pptx | Preliminary Design Review Slide Template
EG207_CDR_Template.pptx | Critical Design Review Slide Template

### 2.3 I&M References and Standards

The following industry standards are applicable to this specification.

Document No. | Title
ISBN 9781439848838 | JOHN G. WEBSTER; HALIT EREN. Measurement, Instrumentation, and Sensors Handbook : Two-Volume Set. Boca Raton: CRC Press, 2014.

SNHU School of Engineering, Technology and Aeronautics (SETA) IDE Building, 2500 North River Rd.

Page 9

## 3 REQUIREMENTS

This section defines the functional, performance, interface, design, resource and project requirements of the System. Please note that the verification requirements are listed in Section 4.

### 3.1 FUNCTIONAL

The System shall satisfy the following functional requirements.

3.1.1 Virtual Instrument Front Panel
The System Virtual Instrument panel display shall provide the following capabilities as described in this section.

3.1.1.1 Sensor Reading and Indications
The display shall provide numeric indicators for each sensor reading and a corresponding pair of LED indications for “Warning” and “Alarm” conditions for each reading as described in Section 3.1.3.

3.1.1.2 Sensor Controls
The display shall provide the necessary controls to operate the sensor package including an Arduino Power On and STOP buttons.

3.1.1.3 Operation Indications
The display shall indicate the current system configuration and operating mode.

3.1.1.4 Calibration Updates
The display shall provide the ability to update the calibration parameters for the Visible Light photoresistor and Water Level sensor through the front panel via numerical controls.

3.1.2 Sensor Update/Read Rate
The System shall read each sensor (identified in Section 1.1) at a rate which is consistent with the response of each sensor such that measurement noise is minimized and the System monitoring performance is stable. The System shall display a reasonable set of sensor measurements in real-time and with appropriate units.

3.1.3 Warning and Alarm Indication
The System shall provide an indication of warning or alarm for each type of measurement within the sensor prototype. This indication shall appear on the instrument display as independent “Warning” and “Alarm” LEDs for each measurement. These LEDs must be positioned to the right of the sensor numerical indicator. These LED indications may be based on the criteria given in Table 2. If different limits are used, they must be formally specified.
Requirement | Sensor | Warning | Alarm
3.1.3.1 | Temperature, T | 85 °F ≤ T ≤ 100 °F | T > 100 °F
3.1.3.2 | Humidity, RH | 30% ≤ RH ≤ 40% | RH < 30%
3.1.3.3 | Visible Light, V | 700lux ≤ V ≤ 1000lux | V > 1000lux
3.1.3.4 | UV Light, U (ADC Level) | 300 ≤ U ≤ 600 | U > 600
3.1.3.5 | Water Level, W | W < 0.5mm or 6mm ≤ W ≤ 10mm | W > 10mm

Table 2. Sensor Warning and Alarm Limits

SNHU School of Engineering, Technology and Aeronautics (SETA) IDE Building, 2500 North River Rd.

Page 10

3.1.4 Waveform Display
The prototype shall display real-time measurement data for at least two sensors on a LabVIEW front panel waveform chart. The sensor readout rate and LabVIEW data collection rates shall be optimized so there is no “dropout” of measurement data on the waveform charts.

3.1.5 Data Logging
The System shall provide the capability of logging each environmental measurement and LED indication using LabVIEW functions. This data shall be time-stamped and be written to an external file for every 8-hour shift. Each file shall possess a filename structure which indicates the date and shift the data was logged. The frequency of data logging (number of updates between data writes) shall be an input on the System instrument panel.

3.1.6 Operational Modes
The System shall operate on a continuous, uninterrupted basis. An additional operating mode such as diagnostics or calibration mode may be implemented and controlled from the System virtual instrument panel. The System shall provide a clear indication of its present operating mode on the panel.

### 3.2 PERFORMANCE

The System shall satisfy the performance requirements specified in this section.

3.2.1 Sensor Accuracy
The System shall measure the environmental variables specified in Section 1.1 to the accuracies (or better than those) listed in Table 3.

Table 3. Sensor Accuracy
Requirements
3.2.2 Sensor | Precision
The System sensors | shall
provide the
measurement | precision
better than or equal to those precisions listed in Table 4.
Reqt | Environmental Variable | Precision
3.2.2.1 | Temperature | 2 °C
3.2.2.2 | Humidity | 2 %
3.2.2.3 | Visible Illuminance | 20 lux
3.2.2.4 | UV Light Intensity | N/A
3.2.2.5 | Water Collection | 0.2 mm
Table 4. Sensor Precision Requirements

3.2.3 Calibration or Diagnostics
The System shall provide the means to perform a calibration of the sensors or a limited diagnostic check on the system health. This function shall be controlled by an input on the System panel with a clear indication of its operational mode.
Reqt | Environmental Variable | Accuracy
3.2.1.1 | Temperature | ± 2.5 °C
3.2.1.2 | Humidity | ± 7%
3.2.1.3 | Visible Illuminance | 10%
3.2.1.4 | UV Light Intensity | N/A
3.2.1.5 | Water Collection | ±1 mm


SNHU School of Engineering, Technology and Aeronautics (SETA) IDE Building, 2500 North River Rd.

Page 11

### 3.3 INTERFACE

The System shall satisfy the interface requirements specified in this section.

3.3.1 Mounting
The System shall satisfy the mounting requirements specified herein.

3.3.1.1 Baseplate Bottom Surface
The System shall include a metallic baseplate which provides a flat underside surface that will rest on a flat surface. The baseplate shall also include tapped holes at each corner to allow securing the housing cover to the baseplate. These holes should be tapped as a Class 2B #6-32UNC thread.

3.3.1.2 Housing Cover to Baseplate
The System housing cover shall mount to its baseplate through 4 holes at the corner of the baseplate and cover profile. The housing cover shall provide clearance holes at these locations such that fasteners can secure the cover to the baseplate.

3.3.1.3 Arduino MEGA 2560 Mounting
The Arduino MEGA 2560 mounting (stand-off) outline in shown in Figure 2.

Figure 2. Arduino MEGA 2560 Mounting Outline

3.3.2 Electrical
The System sensors shall be fully powered by the power busses available on the Arduino microcontroller. Use of external power supplies is not allowed. The sensors shall be seated in one of the ELEGOO kit breadboards as part of its breadboard configuration. The complete System Sensor setup (including wiring to the Arduino) shall be documented.

3.3.3 Data and Power Access
The System shall allow access to the Arduino MEGA 2560 USB and power connectors with the MEGA board mounted on its baseplate and its housing cover in place mounted to the baseplate.

SNHU School of Engineering, Technology and Aeronautics (SETA) IDE Building, 2500 North River Rd.

Page 12

### 3.4 DESIGN

The System shall satisfy the design requirements specified herein.

3.4.1 Housing Design
The housing shall satisfy the following requirements;

3.4.1.1 Mounting Interface
The housing design shall be compatible with the mounting interface specified in Section 3.3.1.2.

3.4.1.2 Exposed Housing Edges
The housing shall not possess sharp exposed edges or sharp points.

3.4.1.3 Housing Fabrication
The housingshall allow fabrication by 3-D printing processes.

3.4.1.4 Rain Bucket Accommodation
The housing shall accommodate the positioning and retention of a rain bucket which is completely sealed such that the housing shall not be exposed to moisture.

3.4.2 Baseplate Design
The System baseplate shall satisfy the requirements specified in this subsection

3.4.2.1 Size
The System baseplate shall be designed as a 8” x 8” x ½" Aluminum 6061-T6 plate.

3.4.2.2 Arduino Board Support
The baseplateshall include clearance holes with underside counterbores to secure the Arduino Mega 2560 via five standoffs to the baseplate (see Section 3.3.1.3).

3.4.2.3 Arduino Board Standoff Screws
The baseplate shall provide clearance holes which accept M2.5 screws and the counterbore depth shall be compatible with the following M2.5 fastener lengths; 6 mm, 8 mm, 10 mm, 12mm and 16mm. The team shall identify which length of M2.5 fasteners will be used.

3.4.3 Electrical Design
The System electrical design shall minimize electronic noise, provide stable sensor readouts and be properly grounded.

3.4.4 Hardware
The mechanical hardware used to secure the cover to the baseplate shall be #6-32UNC fasteners of one of the following lengths; 3/8 in.,1/2 in. or 5/8 in..

### 3.5 PROJECT

The Project Team shall satisfy the following requirements in the execution of this project.

3.5.1 Team Structure
Each team member shall serve as the Team Leader for at least a two-week period. This person shall work with the team to schedule and execute the necessary activities to accomplish the objectives of this project. This person shall also be

SNHU School of Engineering, Technology and Aeronautics (SETA) IDE Building, 2500 North River Rd.

Page 13

responsible for forwarding on all required team communications to the customer as described in the next section. All team decisions made shall be made by a fully democratic process.

3.5.2 Team Communications
Each member of each team will be responsible for providing a series of three written pieces of communication as part of this project. The team will be prompted by the customer when these communications are due. These communications shall consist of the following;
1) A short technical memorandum from each team member (including the team leader) to the team leader providing a technical summary of a technical analysis performed by the team member. This correspondence is due at the time of the Preliminary and Critical Design Review presentations defined in Section 3.5.3,
2) An email assessment of an impact made by a change in this project specification. The customer shall determine when this assessment is required.
3) While serving as Team Leader, a weekly email status report each Friday detailing the tasks that were completed during the week, the tasks planned for the coming week and indication of any pending/current problems or issues.

3.5.3 Preliminary and Critical Design Review Presentations
Each team shall provide short presentations summarizing the state of their system designs at two design reviews; a Preliminary Design Review (three weeks after specification release) and a Critical Design Review (approximately 4 weeks before project completion). MS-Powerpoint presentation templates shall be provided to each team which explicitly lists the information which the customer will expect to see presented at this review.

3.5.4 System Fabrication
Each team shall designate at least one member responsible for manufacture of the baseplate in the SETA IDEA Lab and another member responsible for 3-D printing of the Sensor housing cover. The baseplate design should be completed early to allow the baseplate manufacturing process ample time for the baseplate manufacture. It is strongly recommended that baseplate manufacture begins immediately after returning from the Fall break in October 2021. The 3-D printing file and drawing should be available in mid-November 2021.

3.5.5 System Demonstration
Each team will be required to demonstrate that their final System meets the requirements of this specification. This should be verified before the final Verification process is instructed by the Instructor. With the team’s system running, the Instructor will stimulate each sensor and observe the VI readings and warning/alarm indication. Each team shall submit a verification report detailing this compliance. A Verification Report template (MS-Word) shall be provided to each team for additional guidance.

3.5.6 System Acceptance Data Package (ADP)
Each team will provide the following documentation in support of their system development;
1) Inventor model files (*.ipt,*.iam) for the sensor package assembly,
2) Inventor STL file of the sensor housing cover and an outline drawing of the cover,
3) Sensor package baseplate part files and fabrication drawing,
4) Sensor limits and decision-making flowchart,
5) Characterization Plots for Visible Light and Water Collection Sensors,

SNHU School of Engineering, Technology and Aeronautics (SETA) IDE Building, 2500 North River Rd.

Page 14

6) System Electrical Circuit Diagram (including Arduino) with photographs of breadboard setup,
7) Final LabVIEW VI file (*.vi) and Arduino Code Listing (*.ino),
8) Example System Data Log file, and
9) Verification Report

SNHU School of Engineering, Technology and Aeronautics (SETA) IDE Building, 2500 North River Rd.

Page 15

## 4 VERIFICATION AND TEST REQUIREMENTS

The Project Team shall verify the System satisfies the requirements specified herein in accordance with the requirements set forth in this section.

### 4.1 VERIFICATION MODELS

A breadboard of the System shall be designed, fabricated assembled and developmentally-tested as part of this project.

### 4.2 VERIFICATION COMPLIANCE

The Project Team shall verify the System performance and function in accordance with the details listed in this section and Table 5.

Table 5. System Verification Compliance Matrix

| METHODS: | MODELS: | PHASES:
| (A)nalysis | 1. Prototype (PR)/Breadboard (BB) | Developmental (D)
| (D)emonstration | 2. Engineering Model (EM) | Qualification (Q)
| (I)nspection | 3. Structural Model (SM) | Protoflight (P)
| (M)easurement | 4. Qualification Model (QM) | Flight Acceptance (FA)
| (S)imilarity | 5. Protoflight (PFM)
| (T)est | 6. Flight Model (FM)
| (V)alidation of Records
Req. Ref. | Title | Method | Notes/Basis
3.1 FUNCTIONAL REQUIREMENTS
3.1.1 | Virtual Instrument Front Panel | D,I
3.1.2 | Sensor Update/Read Rate | A,D
3.1.3 | Warning and Alarm Indication | D,T | Sensor warning and alarm limits and decision-making flow chart req’d. Specify if different limits used.
3.1.4 | Waveform Display | D
3.1.5 | Data Logging | D,I | Data file to be provided in ADP
3.1.6 | Operational Modes | D | Flowchart provided for each mode in ADP; Front Panel to ID mode

3.2 PERFORMANCE REQUIREMENTS
3.2.1 | Sensor Accuracy | V | Standard to be used for accuracy determination
3.2.2 | Sensor Precision | A,V | Standard deviation analysis req’d
3.2.3 | Calibration or Diagnostics | D | Calibration Plan required in ADP. Calibration to be performed upon initial assembly.

3.3 INTERFACE REQUIREMENTS
3.3.1 | Mounting | A,D
3.3.1.1 | Baseplate Bottom Surface | D
3.3.1.2 | Housing to Baseplate | D

SNHU School of Engineering, Technology and Aeronautics (SETA) IDE Building, 2500 North River Rd.

Page 16

3.3.2 | Electrical | V,D | System Electrical Circuit Diagram req’d (including Arduino functions)
3.3.3 | Data Power and Access | D
3.4 DESIGN REQUIREMENTS
3.4.1 | Housing | N/A
3.4.1.1 | Mounting Interface | I,D | Inspection of baseplate and cover drawings
3.4.1.2 | Exposed Edges | I | Inspection of cover drawing and cover
3.4.1.3 | Housing Fabrication | D | *STL file and cover drawing required for fabrication
3.4.1.4 | Rain Bucket Accommodation | D | Bucket should seat within cover
3.4.2 | Baseplate | N/A
3.4.2.1 | Size | I | Confirm via baseplate drawing
3.4.2.2 | Arduino Board Support | D | Fit-check of board with baseplate
3.4.2.3 | Arduino Board Standoff Screws | D | Arduino Board mounting
3.4.3 | Electrical | V
3.4.4 | Hardware | V,I
3.5 PROJECT REQUIREMENTS
3.5.1 | Team Structure | D
3.5.2 | Team Communications | D,I | Weekly email status reports req’d
3.5.3 | PDR and CDR Presentations | D | Presentation Templates provided, reviewed class before presentations
3.5.4 | System Fabrication | D,I | Baseplate part file/fab drawing and Cover STL file/outline drawing req’d
3.5.4 | System Demonstration | D | Instructor executes final verification activity
3.5.5 | System ADP | I | ZIP file of all native files


SNHU School of Engineering, Technology and Aeronautics (SETA) IDE Building, 2500 North River Rd.

Page 17

## 5 SENSOR Datasheets

### 5.1 DHT11 Temperature/Humidity Sensor Specifications

### 5.2 CDS-55 Photoresistor


SNHU School of Engineering, Technology and Aeronautics (SETA) IDE Building, 2500 North River Rd.

Page 18


SNHU School of Engineering, Technology and Aeronautics (SETA) IDE Building, 2500 North River Rd.

Page 19

### 5.3 Parallax 28091 UV Light Sensor

SNHU School of Engineering, Technology and Aeronautics (SETA) IDE Building, 2500 North River Rd.

Page 20

### 5.4 Water Collection Module

This datasheet can be found in the Team Project folder on BrightSpace.

SNHU School of Engineering, Technology and Aeronautics (SETA) IDE Building, 2500 North River Rd.

Page 21

## 6 ACRONYMS AND ABBREVIATIONS

The following acronyms and abbreviations are utilized within this specification.

ASTM | American Society for Testing and Materials
CDR | Critical Design Review
CETA | College of Engineering, Technology and Aeronautics
DC | Direct Current
PDR | Preliminary Design Review
SNHU | Southern New Hampshire University (SNHU)
TBS | To Be Specified

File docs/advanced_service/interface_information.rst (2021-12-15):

Interface Information
=====================

.. warning::
    This section is intended for **developers**, and may be irrelevant unless
    you intend to modify or expand the functionality of :ref:`Normal Use`.

GoldPackets
###########

:ref:`GoldPackets` is a custom designed packet standard, made by Team Gold for the EG-207 CMS.

The format is call/response based and detailed below:

+-------------------------+----------+--------------------+----------+-----------+-----------------------------------------------------------------------------------------------------------------------------------------------------+
|          Inst           |   Byte   |       Reply        |   ACK    |   Fail    |                                                                        Note                                                                         |
+=========================+==========+====================+==========+===========+=====================================================================================================================================================+
| ``v``                   | ``0x76`` | ``v0.1_g70b...\n`` | ``ok\n`` | ``127\n`` | The "Version" Command will return the version as ascii. If it prints ``OK`` at the end it completed otherwise it may raise and print an error code. |
+-------------------------+----------+--------------------+----------+-----------+-----------------------------------------------------------------------------------------------------------------------------------------------------+
| ``w``                   | ``0x77`` | ``127\n``          | ``ok\n`` | ``127\n`` | Print the EEPROM warning, 0 if there is none.                                                                                                       |
+-------------------------+----------+--------------------+----------+-----------+-----------------------------------------------------------------------------------------------------------------------------------------------------+
| ``e``                   | ``0x65`` | ``127\n``          | ``ok\n`` | ``127\n`` | Print the EEPROM error, 0 if there is none.                                                                                                         |
+-------------------------+----------+--------------------+----------+-----------+-----------------------------------------------------------------------------------------------------------------------------------------------------+
| ``W``                   | ``0x45`` | ``127\n``          | ``ok\n`` | ``127\n`` | Clear the EEPROM warning. Will return the warning cleared.                                                                                          |
+-------------------------+----------+--------------------+----------+-----------+-----------------------------------------------------------------------------------------------------------------------------------------------------+
| ``E``                   | ``0x57`` | ``127\n``          | ``ok\n`` | ``127\n`` | Clear the EEPROM error. Will return the error cleared.                                                                                              |
+-------------------------+----------+--------------------+----------+-----------+-----------------------------------------------------------------------------------------------------------------------------------------------------+
| ``+``                   | ``0x2b`` | ``127\n``          | ``ok\n`` | ``127\n`` | DEBUG COMMAND, increments servo pos by 1 value and prints the new setpoint                                                                          |
+-------------------------+----------+--------------------+----------+-----------+-----------------------------------------------------------------------------------------------------------------------------------------------------+
| ``-``                   | ``0x2d`` | ``127\n``          | ``ok\n`` | ``127\n`` | DEBUG COMMAND, decrements servo pos by 1 value and prints the nw setpoint                                                                           |
+-------------------------+----------+--------------------+----------+-----------+-----------------------------------------------------------------------------------------------------------------------------------------------------+
| ``_``                   | ``0x5f`` | ``127\n``          | ``ok\n`` | ``127\n`` | DEBUG COMMAND, sets the servo pos to the ``MIN_DOOR_ANGLE`` and prints the angle                                                                    |
+-------------------------+----------+--------------------+----------+-----------+-----------------------------------------------------------------------------------------------------------------------------------------------------+
| ``=``                   | ``0x3d`` | ``127\n``          | ``ok\n`` | ``127\n`` | DEBUG COMMAND, sets the servo pos to the ``MAX_DOOR_ANGLE`` and prints the angle                                                                    |
+-------------------------+----------+--------------------+----------+-----------+-----------------------------------------------------------------------------------------------------------------------------------------------------+
| ``t``                   | ``0x74`` | ``32.00\n``        | ``ok\n`` | ``127\n`` | Lowercase t will poll the DHT11 for its temperature value and return it at that time.                                                               |
+-------------------------+----------+--------------------+----------+-----------+-----------------------------------------------------------------------------------------------------------------------------------------------------+
| ``h``                   | ``0x68`` | ``32.00\n``        | ``ok\n`` | ``127\n`` | Lowercase h will poll the DHT11 for its humidity value and return it at that time.                                                                  |
+-------------------------+----------+--------------------+----------+-----------+-----------------------------------------------------------------------------------------------------------------------------------------------------+
| ``r``                   | ``0x72`` | ``32.00\n``        | ``ok\n`` | ``127\n`` | Lowercase r will poll the rainflow sensor for its instant flow rate and print it out                                                                |
+-------------------------+----------+--------------------+----------+-----------+-----------------------------------------------------------------------------------------------------------------------------------------------------+
| ``l``                   | ``0x6c`` | ``32.00\n``        | ``ok\n`` | ``127\n`` | Lowercasee l will poll the CDS55 for the most recent average LUX reading.                                                                           |
+-------------------------+----------+--------------------+----------+-----------+-----------------------------------------------------------------------------------------------------------------------------------------------------+
| ``u``                   | ``0x75`` | ``32.00\n``        | ``ok\n`` | ``127\n`` | Lowercase U will poll the UV Sensor for the most recent average UV Index reading.                                                                   |
+-------------------------+----------+--------------------+----------+-----------+-----------------------------------------------------------------------------------------------------------------------------------------------------+
| ``<``                   | ``0x3c`` | ``\n``             | ``ok\n`` | ``127\n`` | DEBUG COMMAND, Create an artificial warning.                                                                                                        |
+-------------------------+----------+--------------------+----------+-----------+-----------------------------------------------------------------------------------------------------------------------------------------------------+
| ``>``                   | ``0x3e`` | ``\n``             | ``ok\n`` | ``127\n`` | DEBUG COMMAND, Create an artificial error.                                                                                                          |
+-------------------------+----------+--------------------+----------+-----------+-----------------------------------------------------------------------------------------------------------------------------------------------------+
| ``D``                   | ``0x44`` | ``0\n``            | ``ok\n`` | ``127\n`` | DEBUG COMMAND, Reset all tuning values to default.                                                                                                  |
+-------------------------+----------+--------------------+----------+-----------+-----------------------------------------------------------------------------------------------------------------------------------------------------+
| ``L<byte><byte><byte>`` | ``TBD``  | ``0\n``            | ``ok\n`` | ``127\n`` | DEBUG COMMAND, used to write new coefficients to the lux sensor.                                                                                    |
+-------------------------+----------+--------------------+----------+-----------+-----------------------------------------------------------------------------------------------------------------------------------------------------+

Communication Example
---------------------

.. code-block:: shell

    > v
    CDR-RELEASE-102-gaf0e-dirty
    ok
    > p
    ?70
    ok

Error Matrix
------------

Warnings:

+--------------+------------------------------------------------------------+
| Warning Code |                            Note                            |
+==============+============================================================+
| 10           | Sensor reading was out of scope or NaN                     |
+--------------+------------------------------------------------------------+
| 15           | Door was left ajar or rain sensor was left on              |
+--------------+------------------------------------------------------------+
| 69           | Self-inflicted warn, written by the LabView to the arduino |
+--------------+------------------------------------------------------------+

Errors:

+------------+-------------------------------------------------------------+
| Error Code |                            Note                             |
+============+=============================================================+
| 69         | Self-inflicted error, written by the LabView to the arduino |
+------------+-------------------------------------------------------------+

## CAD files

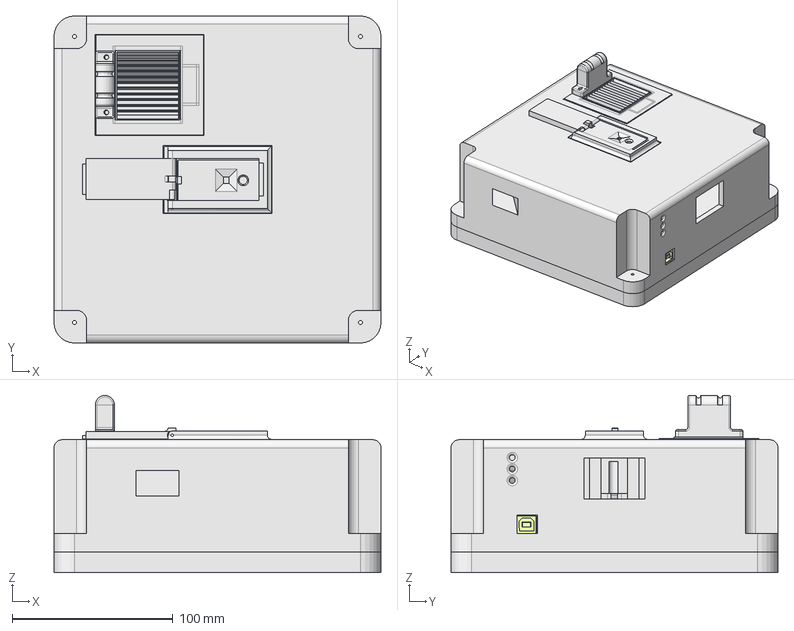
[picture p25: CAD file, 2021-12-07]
CAD/SensorAssembly.FCStd
203.2 x 203.2 x 110.0 mm
BasePlate_001
SensorBody_001
Standoff_Body_001
Standoff_Body_002
Standoff_Body_003
Standoff_Body_004
ImportedArduino_ArduinoMega_STEP_AP203_001
Door Assembly_001
Rain Flow Sensor Trap_001
Rain Flow Sensor Service Cover_001
Rain Flow Sensor Grate_001

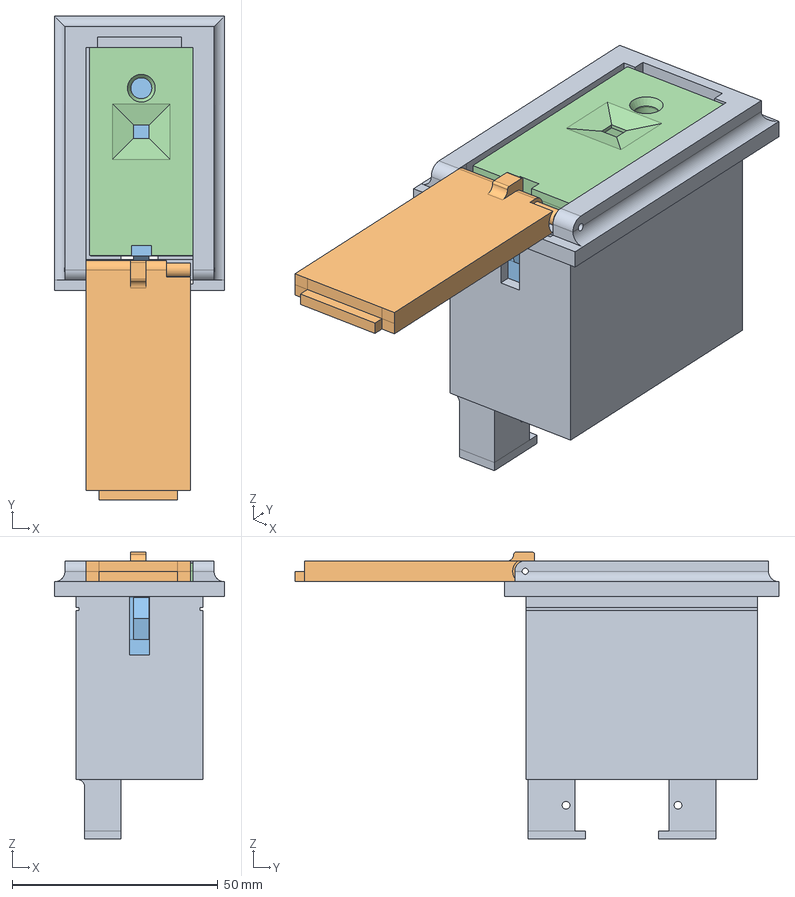
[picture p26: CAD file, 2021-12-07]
CAD/Light Sensor Door/Door Assembly.FCStd
41.3 x 117.5 x 69.6 mm
Door Frame_001
Door Cover_001
Sensor Shuttle Base_001
Sensor Shuttle_001

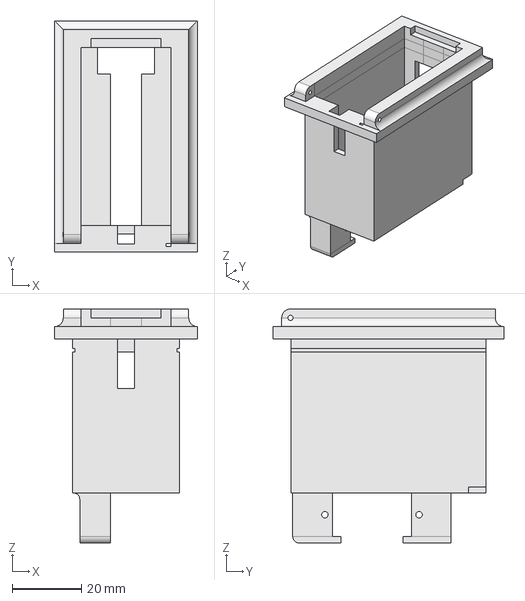
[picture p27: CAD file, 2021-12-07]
CAD/Light Sensor Door/Door Frame.FCStd
41.3 x 66.7 x 67.5 mm

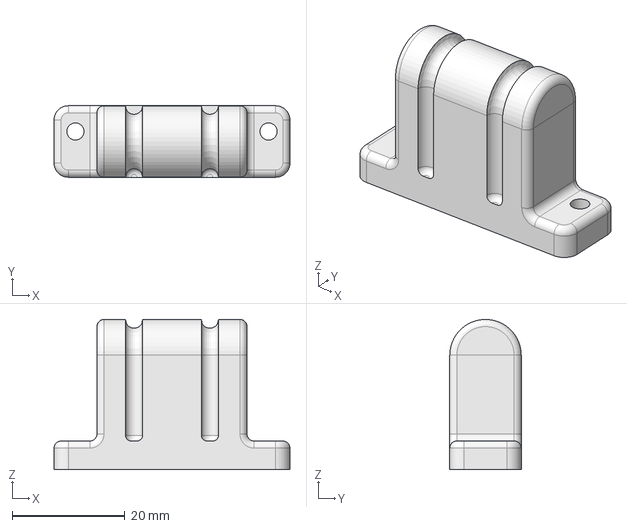
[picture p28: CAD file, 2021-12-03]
CAD/Rain Flow Sensor/Rain Flow Sensor Service Cover.FCStd
41.9 x 12.7 x 26.7 mm

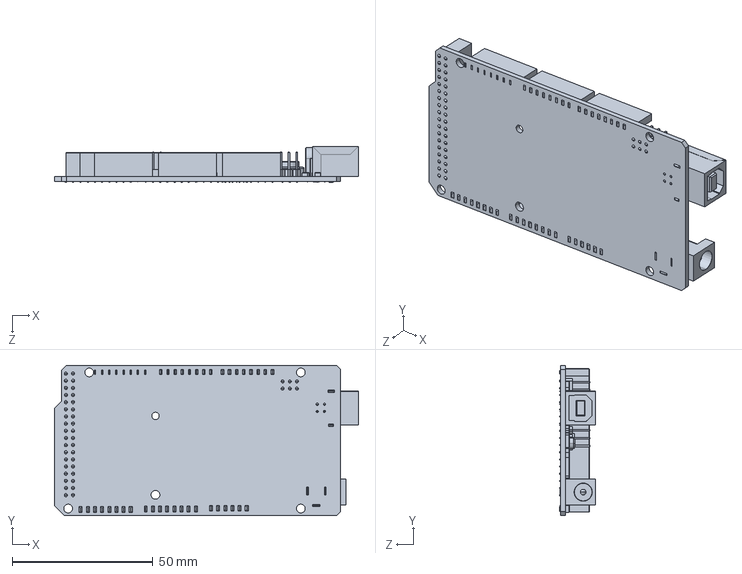
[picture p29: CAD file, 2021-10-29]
CAD/Resources/ArduinoMega_STEP_AP203.STEP
107.9 x 53.4 x 13.0 mm

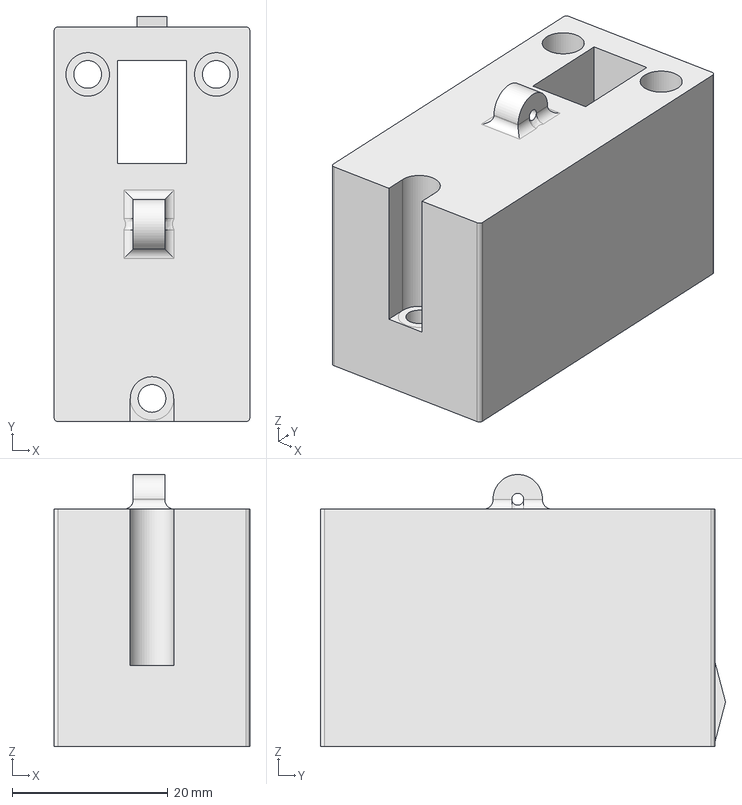
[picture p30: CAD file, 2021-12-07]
CAD/Light Sensor Door/Sensor Shuttle Base.FCStd
25.1 x 52.0 x 34.9 mm

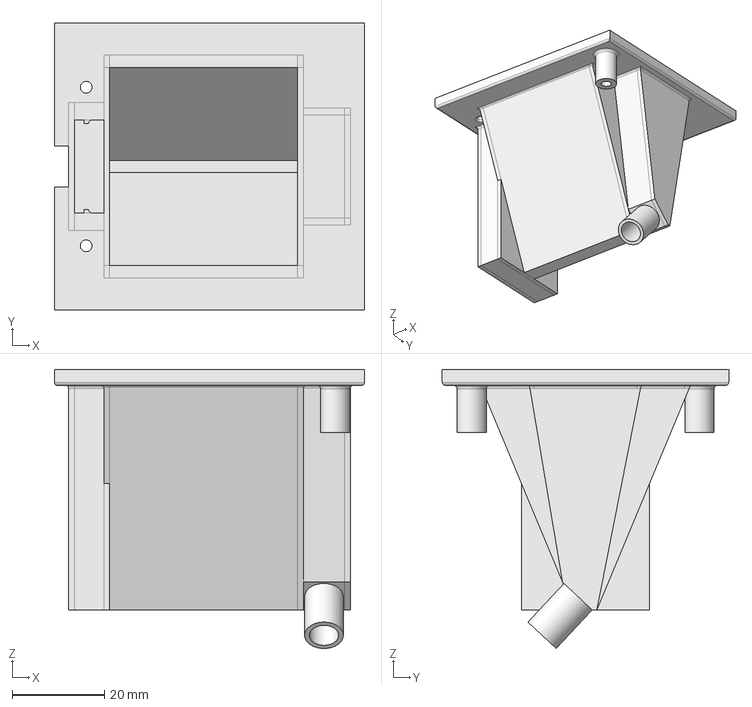
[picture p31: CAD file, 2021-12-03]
CAD/Rain Flow Sensor/Rain Flow Sensor Trap.FCStd
67.1 x 62.0 x 60.4 mm

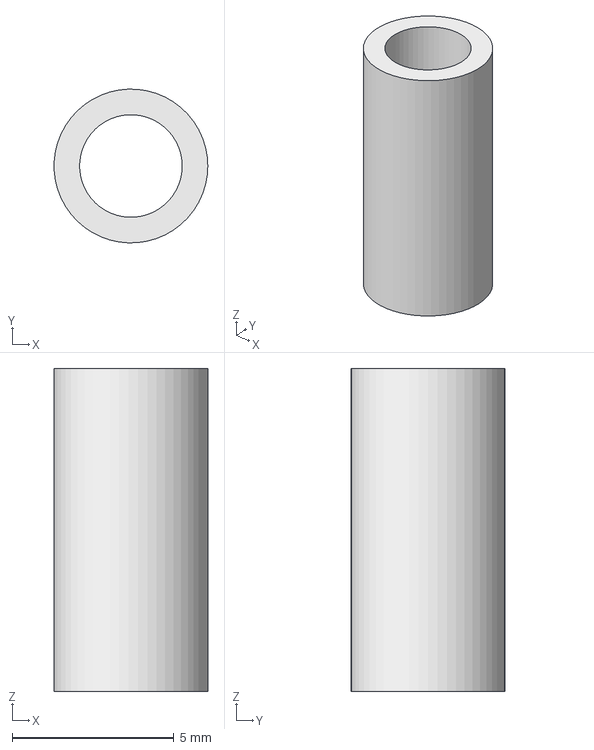
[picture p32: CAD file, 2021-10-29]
CAD/Resources/Standoff.FCStd
4.76 x 4.76 x 10.0 mm

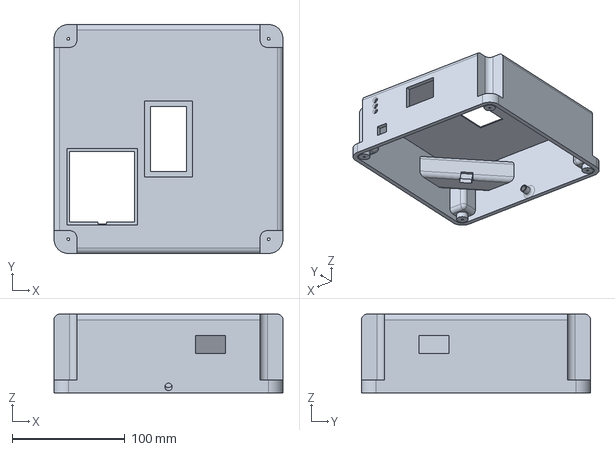
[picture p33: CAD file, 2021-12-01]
CAD/SensorBody.FCStd
203.2 x 203.2 x 69.8 mm

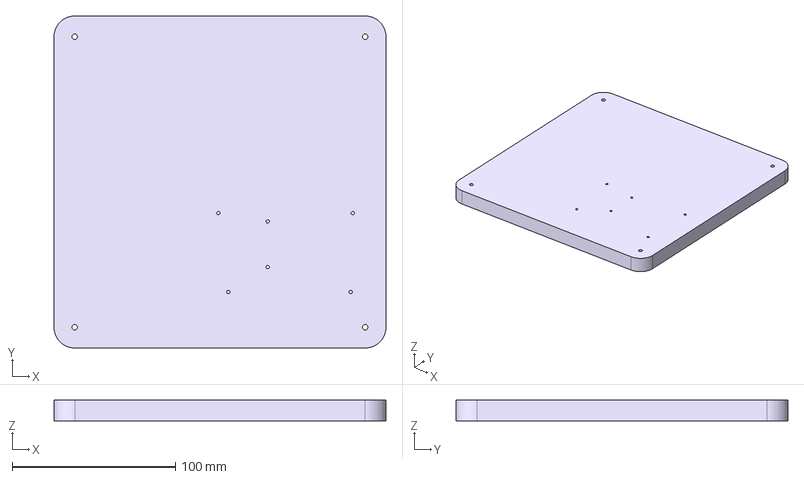
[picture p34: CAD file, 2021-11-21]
CAD/BasePlate.FCStd
203.2 x 203.2 x 12.7 mm

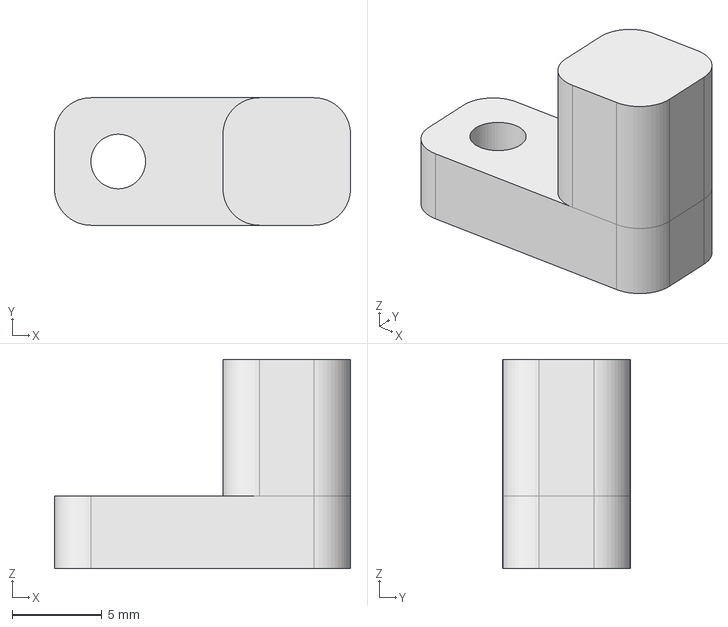
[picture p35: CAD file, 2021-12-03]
CAD/Rain Flow Sensor/Rain Flow Sensor Locks.FCStd
16.5 x 7.11 x 11.7 mm

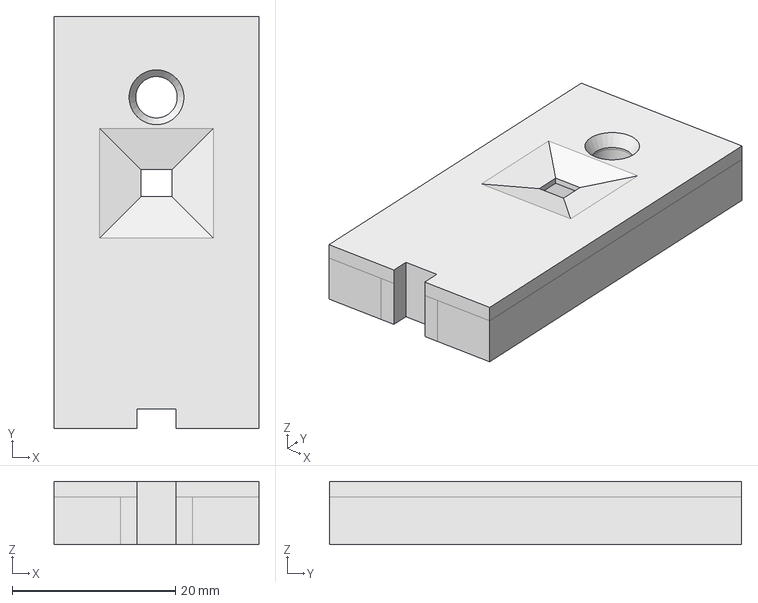
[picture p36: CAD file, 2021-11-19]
CAD/Light Sensor Door/Sensor Shuttle.FCStd
25.1 x 50.5 x 7.75 mm

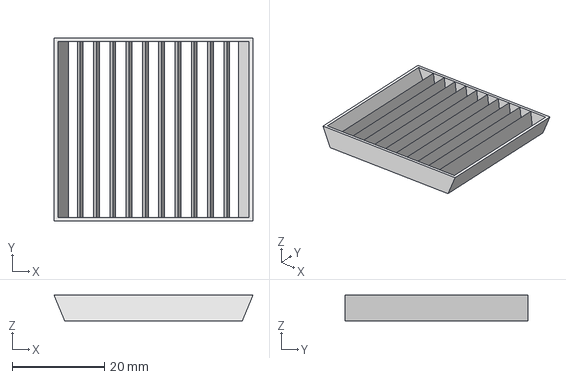
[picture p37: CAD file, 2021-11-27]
CAD/Rain Flow Sensor/Rain Flow Sensor Grate.FCStd
43.2 x 39.8 x 5.59 mm

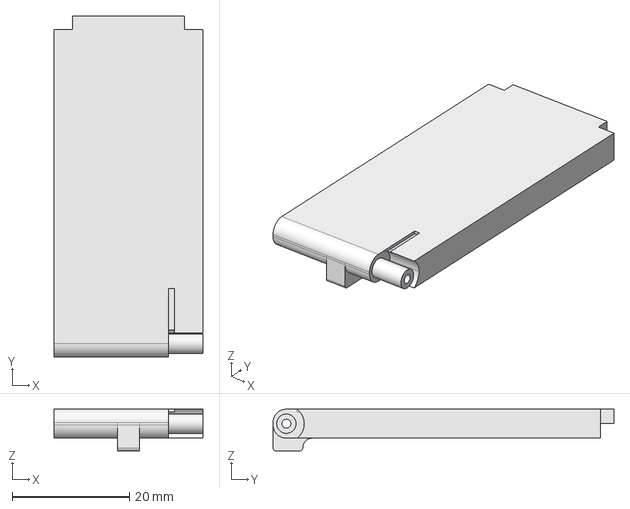
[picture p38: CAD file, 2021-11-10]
CAD/Light Sensor Door/Door Cover.FCStd
25.4 x 58.2 x 7.11 mm

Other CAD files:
CAD/Resources/ImportedArduino.FCStd

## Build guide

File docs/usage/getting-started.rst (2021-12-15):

Getting Started
===============

Introduction
------------

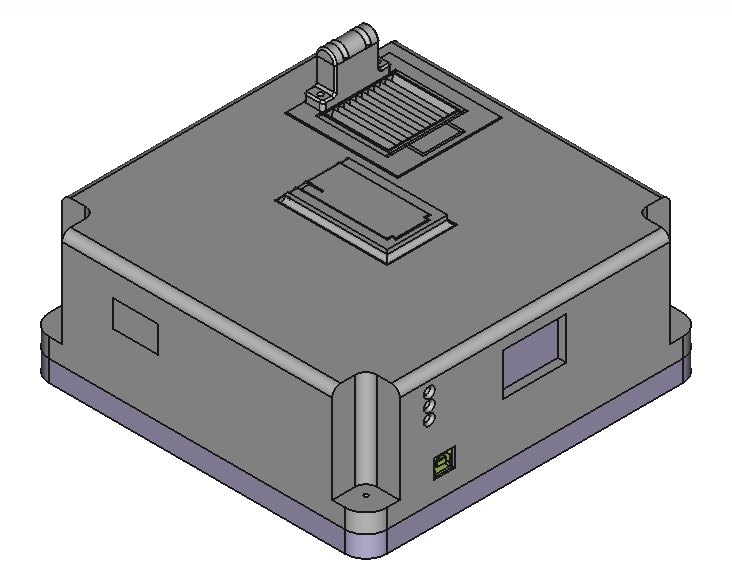
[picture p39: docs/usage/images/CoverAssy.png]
Team Gold Climate Monitoring System


The *Climate Monitoring System* by **Team Gold** is a fully featured scientific climate monitoring instrument,
designed to provide the user with the ability to catalog and record the changes in an outdoor environment over
a period of time.

.. warning::
    Before plugging in your CMS please read :ref:`Light Sensor Aperture` first. Failure to do so may put you
    at risk of damaging your CMS.

Hardware
--------

The CMS is an enclosed unit designed to provide you the user with the ability to record and catalog several
scientific metrics at once. By placing the CMS in some environment, you can record the changes that environment
undergoes over time.

Physical Features
^^^^^^^^^^^^^^^^^

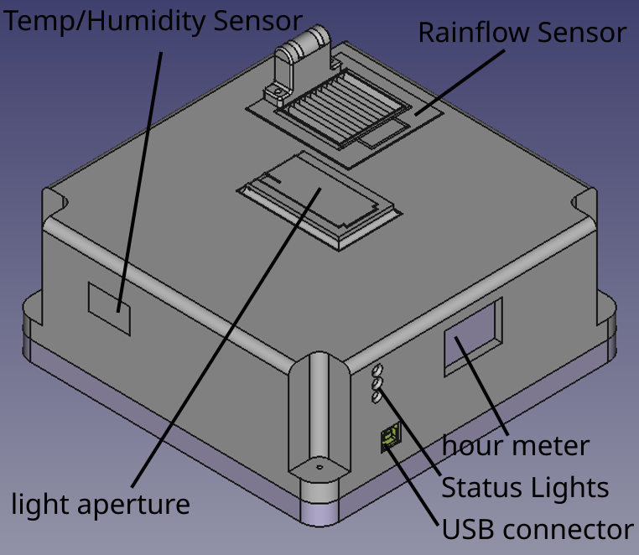
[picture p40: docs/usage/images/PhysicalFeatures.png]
Physical Features


USB Connector
^^^^^^^^^^^^^

Your CMS comes equipped with a USB type B connector, used for plugging your sensor into a laptop, desktop or embedded
system.

Light Sensor Aperture
^^^^^^^^^^^^^^^^^^^^^

The light sensor Aperture is a component of your CMS used to catalog and sense the presence and intensity of both *UV Light*
as well as *Visible Light*.

.. warning::
    Please be aware, the :ref:`Light Sensor Aperture` may move upon startup, please confirm the following on your sensor
    before turning it on for the first time.

    - Your :ref:`Light Sensor Aperture` is closed and or fully open
    - The space around your :ref:`Light Sensor Aperture` is free of objects or hazards

Temp/Humidity Opening
^^^^^^^^^^^^^^^^^^^^^

The opening on the rear left corner of the CMS allows for air to flow through an internal channel and be read by the sensor within
it is important that this covering is free of debris and is not at risk of collecting debris, especially outdoors.

.. note::
    Your CMS may have come with masking tape covering the sensor opening, it is important to remove this tape before placing the
    sensor into service.

Rainflow Sensor
^^^^^^^^^^^^^^^

Your CMS can record rainflow in in :sup:`3`/min OR Inches of Rain/Rainfall. You can set the output mode in the LabView :ref:`Software`.

Software
--------

To use the full feature set of your CMS, you must configure the CMS companion software that ships with your sensor.
There are multiple ways to acquire this software, the recommended way is :ref:`With a Release`, but other options exist.

With a Release
^^^^^^^^^^^^^^

By using a specific release, you can be sure that a specific release behaves as its corresponding documentation or for a specific
hardware version, to begin, navigate to the online Releases_ page on github, and follow the instructions to install attached to the
latest release.

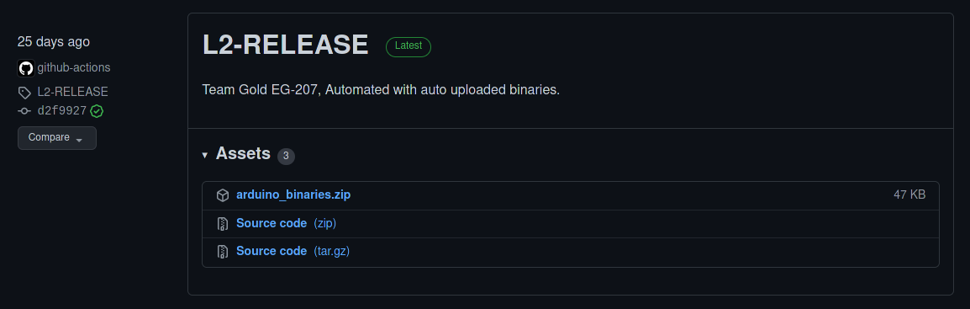
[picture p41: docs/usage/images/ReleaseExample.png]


Using your sensor
-----------------

Once you've collected your *Climate Monitoring System* and configured your software, proceed to the :ref:`Normal Use`
section to learn how to use your sensor.

.. _Releases: https://github.com/KenwoodFox/EG-207-CCEMS/releases/

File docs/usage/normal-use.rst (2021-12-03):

Normal Use
==========

Using the LabView Interface
###########################

Much of the climate monitoring system uses the LabView Interface (link here) shipped with the sensor as software.

LabView Front Panel

The LabView front panel allows the user to do all tasks related to the upkeep and function of the sensor.

Errors, Warnings and Alarms
###########################

When the limits of :ref:`Normal Use` are exceeded, your CMS may raise an :ref:`Error`, send a :ref:`Warning`, or raise an :ref:`Alarm`.

Limits
------

.. list-table:: Sensor Limits
   :widths: 50 25 25
   :header-rows: 1

   * - Sensor
     - Warning
     - Alarm
   * - Water Flow Sensor
     - less than 0.5in
     - (Slightly under 'flow over' max)

Error
-----

An error is an issue with the sensor overseer system, examples of error are things like the light sensor door being unable to
open, a disconnect in a sensor, a USB reset or a filesystem error on the laptop. Errors when raised are stored in the EEPROM,
and can be read out via the LabView interface.

Warning
-------

A warning is triggered by a sensor approaching some known limit or by some other function of the system approaching a limit or max.
Examples include UV radiation in excess of normal values, a firmware upgrade being halted, or a failed sensor autocal. They are read
from the EEPROM and can be displayed via the LabView interface.

Alarm
-----

An alarm code is raised when a sensor exceeds safe ranges for operation, for example, UV radiation that may damage the sensor, extreme
heat that could overwhelm the DHT11's paper components, or a water level/submersion that may overcome the foam and rubber gaskets of the
sensor housing.

When an alarm code is raised, its value is stored in EEPROM, and, if possible, "Evasive Measures" are taken to protect the sensor, such as:

- Shutting down individual sensor power
- Closing the light sensor door
- Triggering a USB reset

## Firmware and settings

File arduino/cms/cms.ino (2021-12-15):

// EG-207, SNHU
// Team Gold

// Public libraries
#include <Arduino.h>
#include <Servo.h>
#include <DHT.h>
#include <EEPROM.h>

// Config/Build
#include "constants.h"
#include "version.h"
#include "memory.h"

// Sensors
#include "sensors/WaterLevelSensor.cpp"
#include "sensors/CDS55.cpp"
#include "sensors/ParallaxUVSensor.cpp"

// Construct Sensor Objects
WaterLevelSensor rainFlow = WaterLevelSensor(ANALOG_WATER, ENABLE_WATER);
UVSensor uvSensor = UVSensor(ANALOG_UVSENSOR);
CDS55 cds55 = CDS55(ANALOG_CDS55);
DHT dht(DATA_DHT11, DHT_TYPE);

// Other objects
Servo lightSensorDoorServo;

void setup()
{
  // Init serial
  Serial.begin(115200);

  // Initialize sensors
  dht.begin();

  // Initalize others
  lightSensorDoorServo.attach(LIGHT_SENSOR_SERVO);

  // Setup Status LEDs
  pinMode(STATUS_LED, OUTPUT);
  pinMode(WARN_LED, OUTPUT);
  pinMode(ERROR_LED, OUTPUT);

  // Initalize RAM values
  pos = MIN_DOOR_ANGLE;
}

void loop()
{
  // Update RAM values
  EEPROM.get(WARN_ADDR, warn);
  EEPROM.get(ERROR_ADDR, error);

  // Move this somewhere else
  inst_temp = dht.readTemperature() + EEPROM.read(BIAS_TEMP);
  inst_humidity = dht.readHumidity() + EEPROM.read(BIAS_HUMIDITY);
  lightSensorDoorServo.write(pos);
  inst_flow = rainFlow.getCubicInches();
  inst_lux = cds55.getLuxValue();
  inst_uv = uvSensor.getRawValue();

  // Blink Status LEDs with loop counter
  if (LC < 84 && COMMAND)
  {
    digitalWrite(STATUS_LED, HIGH);
  }
  else
  {
    digitalWrite(STATUS_LED, LOW);
  }
  if (LC == 84)
  {
    COMMAND = false;
  } // Clears command at end of STATUS_LED cycle.
  if (LC >= 84 && LC < 168 && warn != 0)
  {
    digitalWrite(WARN_LED, HIGH);
  }
  else
  {
    digitalWrite(WARN_LED, LOW);
  }
  if (LC >= 168 && error != 0)
  {
    digitalWrite(ERROR_LED, HIGH);
  }
  else
  {
    digitalWrite(ERROR_LED, LOW);
  }

  // Cleanup mainloop.
  cleanup();

  // This is one of the few holding commands in our program, it scales excecution speed.
  delay(4);
}

void cleanup()
{
  // Cleanup tasks to be run at the END of the mainloop

  // Check for ACK at end of instruction.
  if (ACK)
  {
    Serial.println("ok"); // Send ACK.
    ACK = false;          // Reset ACK flag.
  }

  // Handlers
  // Handler for wet_cond_while_sensor_door open should go here, and it should set pos to MIN

  // Timeout Control
  if (!streamerMode)
  { // If not streamer mode
    if (pos == MAX_DOOR_ANGLE && LC == 254)
    {
      door_ajar_timeout++;
    } // Increment once per loop.
    if (pos == MIN_DOOR_ANGLE)
    {
      door_ajar_timeout = 0;
    } // Reset when done.
    if (door_ajar_timeout == door_ajar_wait && pos != MIN_DOOR_ANGLE)
    {
      pos = MIN_DOOR_ANGLE;
      EEPROM.put(WARN_ADDR, 15);
      door_ajar_timeout = 0;
    } // Close door on timeout, raise warning, etc
  }

  // This is where limit checks come in.
  if (inst_lux > 7000)
  {
    EEPROM.put(WARN_ADDR, 10);
  } // TODO: This is broken
  if (inst_lux > 5800)
  {
    EEPROM.put(ERROR_ADDR, 10);
  } // TODO: This is broken
  if (inst_temp > 85)
  {
    EEPROM.put(WARN_ADDR, 10);
  }
  if (inst_temp > 100)
  {
    EEPROM.put(ERROR_ADDR, 10);
  }
  if (inst_flow > 180)
  {
    EEPROM.put(WARN_ADDR, 10);
  }
  if (inst_flow > 210)
  {
    EEPROM.put(ERROR_ADDR, 10);
  }

  if (streamerMode && LC % 100 == 0)
  {
    csvStreamer();
  }

  // Increment LC
  LC++;
}

void csvStreamer()
{
  // Final function of the CMS, all this needs to do is stream a csv out to the python home application.
  Serial.print("%time"); // python will tag this for us.
  Serial.print(",");
  Serial.print(inst_temp);
  Serial.print(",");
  Serial.print(inst_humidity);
  Serial.print(",");
  if (pos == MAX_DOOR_ANGLE)
  {
    Serial.print(inst_lux);
    Serial.print(",");
    Serial.print(inst_uv);
  }
  else
  {
    Serial.print(-1);
    Serial.print(",");
    Serial.print(-1);
  }
  Serial.print(",");
  Serial.println(inst_flow);
}

void serialEvent()
{
  // Serial event is called when the serial buffer has an instruction.
  // noInterrupts(); // Do not be interrupted

  // As long as serial data is available
  while (Serial.available())
  {
    COMMAND = true; // Raise the command flag.

    // Switch on serial.read single instruction.
    int instruct = Serial.read();

    switch (instruct)
    {
    case 0x76:                 // Instruction v
      Serial.println(VERSION); // Print Version
      break;

    case 0x65:               // Instruction e
      Serial.println(error); // Print the error
      break;

    case 0x77:              // Instruction w
      Serial.println(warn); // Print the warning
      break;

    case 0x45:                   // Instruction E
      EEPROM.put(ERROR_ADDR, 0); // Clear EEPROM Error
      Serial.println(error);     // Print the error we just cleared.
      break;

    case 0x57:                  // Instruction W
      EEPROM.put(WARN_ADDR, 0); // Clear EEPROM warning
      Serial.println(warn);     // Print the warning we just cleared.
      break;

    case 0x74: // Instruction t
      // Returns the instant temp of the dht 11

      if (!isnan(inst_temp))
      {
        Serial.print("T");
        Serial.println(inst_temp);
      }
      else
      {
        Serial.println("?");
        EEPROM.put(WARN_ADDR, 10);
      }
      break;

    case 0x54: // Instruction T
      // Sets the bias for the temp sensor
      EEPROM.put(BIAS_TEMP, Serial.read());

      Serial.println("0");

      break;

    case 0x68: // Instruction h
      // Returns the instant humidity of the dht 11

      if (!isnan(inst_humidity))
      {
        Serial.print("H");
        Serial.println(inst_humidity);
      }
      else
      {
        Serial.println("?");
        EEPROM.put(WARN_ADDR, 10);
      }
      break;

    case 0x48: // Instruction H
      // Sets the bias for the humidity sensor
      EEPROM.put(BIAS_HUMIDITY, Serial.read());

      Serial.println("0");

      break;

    case 0x72: // Instruction r
      // Returns the instant water flow rate

      inst_flow = rainFlow.getCubicInches();

      if (!isnan(inst_flow))
      {
        Serial.print("R");
        Serial.println(inst_flow);
      }
      else
      {
        Serial.println("?");
        EEPROM.put(WARN_ADDR, 10);
      }
      break;

    // All these for light door sensor
    case 0x2b:
      pos++;
      Serial.println(pos);
      break;

    case 0x2d:
      pos--;
      Serial.println(pos);
      break;

    case 0x3d:
      pos = MAX_DOOR_ANGLE;
      Serial.println(pos);
      break;

    case 0x5f:
      pos = MIN_DOOR_ANGLE;
      Serial.println(pos);
      break;

    case 0x6c: // Instruction l
      // Returns the instant lux level

      inst_lux = cds55.getLuxValue();

      if (!isnan(inst_lux))
      {
        Serial.print("L");
        Serial.println(inst_lux);
      }
      else
      {
        Serial.println("?");
        EEPROM.put(WARN_ADDR, 10);
      }
      break;

    case 0x4c: // Instruction L
      // Sets the lux sensor coefs
      EEPROM.put(COEF_PHOTO_A, Serial.read());
      EEPROM.put(COEF_PHOTO_B, Serial.read());
      EEPROM.put(COEF_PHOTO_C, Serial.read());

      Serial.println("0");

      break;

    case 0x75: // Instruction u
      // Returns the instant uv index

      inst_uv = uvSensor.getRawValue();

      if (!isnan(inst_uv))
      {
        Serial.print("U");
        Serial.println(inst_uv);
      }
      else
      {
        Serial.println("?");
        EEPROM.put(WARN_ADDR, 10);
      }
      break;

    case 0x3c:
      // Trigger a self imposed warning.
      EEPROM.put(WARN_ADDR, 69);
      break;

    case 0x3e:
      // Trigger a self imposed error.
      EEPROM.put(ERROR_ADDR, 69);
      break;

    case 0x44: // Instruction D
      // "Default" Instruction, not to be confused with the case default, it just defaults all the values
      EEPROM.put(COEF_PHOTO_A, COEF_PHOTO_A_DEFAULT);
      EEPROM.put(COEF_PHOTO_B, COEF_PHOTO_B_DEFAULT);
      EEPROM.put(COEF_PHOTO_C, COEF_PHOTO_C_DEFAULT);
      EEPROM.put(BIAS_TEMP, BIAS_HUMIDITY_DEFAULT);
      EEPROM.put(BIAS_HUMIDITY, BIAS_HUMIDITY_DEFAULT);

      Serial.println("0");
      break;

    case 0x73:
      // Toggles streamer mode
      if (streamerMode)
      {
        streamerMode = false;
      }
      else
      {
        streamerMode = true;
      }

    case 0x53:
      // Like streamer mode but, only does it once.
      csvStreamer();
      break;

    default:
      // Bad or unknown instruction

      // Check eeprom
      if (error != 0)
      {
        Serial.print("E");
        Serial.println(error);
      }
      else if (warn != 0)
      {
        Serial.print("W");
        Serial.println(warn);
      }
      else
      {
        Serial.print("?");
        Serial.println(instruct, HEX);
      }
      break;
    }

    ACK = true; // Raise ACK flag.
  }

  // interrupts(); // Resume being interrupted.
}

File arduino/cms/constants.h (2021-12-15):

// Water Sensor
#define ENABLE_WATER 12
#define ANALOG_WATER 0

// LEDs
#define STATUS_LED 11
#define WARN_LED 10
#define ERROR_LED 9

// CDS 55
#define ANALOG_CDS55 1

// UV Sensor
#define ANALOG_UVSENSOR 2

// Light Sensor Servo
#define LIGHT_SENSOR_SERVO 3
#define MAX_DOOR_ANGLE 147 // Last changed dec 7
#define MIN_DOOR_ANGLE 14  // Last changed dec 8

// DHT 11
#define DATA_DHT11 6
#define DHT_TYPE DHT11

// EEPROM Defs
#define WARN_ADDR 15
#define ERROR_ADDR 20

// EEPROM coeficent values
#define COEF_PHOTO_A 25
float COEF_PHOTO_A_DEFAULT = 0.0073;
#define COEF_PHOTO_B 30
float COEF_PHOTO_B_DEFAULT = 2.0616;
#define COEF_PHOTO_C 35
float COEF_PHOTO_C_DEFAULT = 308.12;

#define BIAS_TEMP 40
float BIAS_TEMP_DEFAULT = 0.00;
#define BIAS_HUMIDITY 45
float BIAS_HUMIDITY_DEFAULT = 0.00;

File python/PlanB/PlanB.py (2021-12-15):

import os
import struct
import sys
import csv
import time
import serial
import logging
import coloredlogs
import pyqtgraph as pg

from io import StringIO

from PyQt5.QtCore import QThread, pyqtSignal
from PyQt5.QtGui import QTextBlock


from pathlib import Path

from PyQt5.QtWidgets import (
    QAction,
    QApplication,
    QCheckBox,
    QComboBox,
    QDoubleSpinBox,
    QLabel,
    QMainWindow,
    QMessageBox,
    QProgressBar,
    QPushButton,
    QSpinBox,
    QTextEdit,
)
from PyQt5 import uic
from pyqtgraph import PlotWidget, plot
from serial.serialutil import SerialException


class PlanBAI(QMainWindow):
    def __init__(self):
        # Override
        super(PlanBAI, self).__init__()

        # Create and setup a logger
        self.log = logging.getLogger(__name__)
        coloredlogs.install(level="DEBUG")  # Setup coloredlogs

        # Stuff
        self.last_error = 0
        self.last_warning = 0
        self.last_warnings_check = 0
        self.photosensor_last = 0
        self.photosensor_enable_time = 0

        # Load UI
        self.load_ui()

        # Define/connect our widgets
        self.serialPortCombo = self.findChild(QComboBox, "serialPortComboBox")
        self.serialConnectionLabel = self.findChild(
            QLabel, "serialConnectionLabel"
        )
        self.serialConnectButton = self.findChild(
            QPushButton, "serialConnectButton"
        )

        self.serialLog = self.findChild(QTextEdit, "serialLogWindow")

        self.exitCleanlyDropdown = self.findChild(
            QAction, "actionExit_Cleanly"
        )

        self.graphWidget = self.findChild(PlotWidget, "mainGraph")

        self.enablePollingCheckbox = self.findChild(
            QCheckBox, "enablePollingCheckbox"
        )

        self.enableLightSensorCheckbox = self.findChild(
            QCheckBox, "enablePhotoCheckbox"
        )

        self.photosensorCheckDuration = self.findChild(
            QSpinBox, "timeBetweenPollsSpinbox"
        )

        self.flashPhotoCoefsButton = self.findChild(
            QPushButton, "lightSensorCoefFlashButton"
        )
        self.flashPhotoCoefsStatus = self.findChild(
            QLabel, "lightSensorFlashStatus"
        )

        self.factoryDefaultsButton = self.findChild(
            QPushButton, "factoryDefaultsButton"
        )
        self.factoryDefaultsStatus = self.findChild(
            QLabel, "factoryDefaultsLabel"
        )

        self.flashDHTBiasButton = self.findChild(
            QPushButton, "dht11BiasFlashButton"
        )

        self.tempBiasSpin = self.findChild(QDoubleSpinBox, "tempBiasSpinBox")

        self.humidityBiasSpin = self.findChild(
            QDoubleSpinBox, "humidityBiasSpinbox"
        )

        self.openLightSensorDoorButton = self.findChild(
            QPushButton, "openLightSensorDoorButton"
        )
        self.closeLightSensorDoorButton = self.findChild(
            QPushButton, "closeLightSensorDoorButton"
        )

        self.flowSensorUtilBar = self.findChild(
            QProgressBar, "waterFlowRateBar"
        )

        self.streamToFileDropdown = self.findChild(QAction, "actionSave_CSV")

        self.serialPortCombo.addItems(
            ["/dev/ttyACM0", "/dev/ttyACM1", "COM1", "COM5"]
        )  # Move me somewhere else

        # Attach buttons/functions
        self.serialConnectButton.clicked.connect(self.connectArduino)
        self.exitCleanlyDropdown.triggered.connect(self.exitCleanly)
        self.streamToFileDropdown.triggered.connect(self.streamDataToFile)
        self.flashPhotoCoefsButton.clicked.connect(self.flashPhotoCoefs)
        self.flashDHTBiasButton.clicked.connect(self.flashDHTBias)
        self.factoryDefaultsButton.clicked.connect(self.flashDefaults)

        self.openLightSensorDoorButton.clicked.connect(
            self.openLightSensorDoor
        )
        self.closeLightSensorDoorButton.clicked.connect(
            self.closeLightSensorDoor
        )

        # Style our graphs
        self.time = []
        self.temperatureReading = []
        self.humidityReading = []

        # Set background color to white.
        self.graphWidget.setBackground("w")

        # Add Title
        self.graphWidget.setTitle(
            "Climate Air Conditions", color="b", size="16pt"
        )

        # Add Axis Labels
        tempStyle = {"color": "#f00", "font-size": "20px"}
        humidityStyle = {"color": "#00f", "font-size": "20px"}
        self.graphWidget.setLabel("left", "Temperature (°C)", **tempStyle)
        self.graphWidget.setLabel("right", "Humidity (Rh%)", **humidityStyle)
        self.graphWidget.setLabel("bottom", "Epoch (s)", **tempStyle)

        # Add legend
        self.graphWidget.addLegend()

        # Add grid
        self.graphWidget.showGrid(x=True, y=True)

        # Setup plots
        pen = pg.mkPen(color="r")
        self.tempPlot = self.graphWidget.plot(
            self.time,
            self.temperatureReading,
            name="Temp",
            pen=pen,
            symbolSize=3,
            symbolBrush=("r"),
        )
        pen = pg.mkPen(color="b")
        self.humidityPlot = self.graphWidget.plot(
            self.time,
            self.temperatureReading,
            name="Humidity",
            pen=pen,
            symbolSize=3,
            symbolBrush=("b"),
        )

        # Create tempfiles
        self.temp_data = StringIO()

        self.log.info("Program started!")

        # Show the UI
        self.show()

    def load_ui(self):
        path = os.fspath(
            Path(__file__).resolve().parent / "resources/planb.ui"
        )  # NOQA: E501

        # Load UI frompath
        uic.loadUi(path, self)

    def openLightSensorDoor(self):
        self.arduino.write("=".encode())
        self.arduino.read_all()

    def closeLightSensorDoor(self):
        self.arduino.write("_".encode())
        self.arduino.read_all()

    def warningMessage(self, error_code):
        # Setup popup message box (for errors)
        self.warning_msg_box = QMessageBox()
        self.warning_msg_box.setIcon(QMessageBox.Warning)
        self.warning_msg_box.setText("Sensor reported an warning!")
        self.warning_msg_box.setInformativeText(
            f"Sensor reported an warning code {error_code}"
        )
        self.warning_msg_box.setWindowTitle("CMS Warning")
        self.warning_msg_box.setDetailedText("Details here..")
        self.warning_msg_box.setStandardButtons(
            QMessageBox.Ok | QMessageBox.Cancel
        )
        self.warning_msg_box.buttonClicked.connect(self.clear_warnings)

        self.warning_msg_box.exec_()

    def clear_warnings(self):
        self.arduino.write("W".encode())
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

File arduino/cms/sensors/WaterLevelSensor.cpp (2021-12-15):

// Team Gold
// EG-207, SNHU

// Public libraries
#include "Arduino.h"

class WaterLevelSensor
{
private:
    unsigned int pin;        // What pin the sensor is on
    unsigned int enable_pin; // What pin enables the sensor
    float value;             // The current value of the sensor
public:
    WaterLevelSensor(unsigned int _pin, unsigned int _enable_pin)
    {
        pin = _pin; // Update pins
        enable_pin = _enable_pin;

        pinMode(enable_pin, OUTPUT);
        pinMode(pin, INPUT);

        digitalWrite(enable_pin, HIGH); // Turn off the sensor.
    };

    float getRawValue()
    {
        digitalWrite(enable_pin, LOW);  // Turn on the sensor.
        value = analogRead(pin);        // Read the current sensor value.
        digitalWrite(enable_pin, HIGH); // Disable the sensor when done.
        return value;
    };

    float getCubicInches()
    {
        digitalWrite(enable_pin, LOW); // Turn on the sensor.
        value = analogRead(pin);       // Read the current sensor value.
        value = 0.1 * value;
        digitalWrite(enable_pin, HIGH); // Disable the sensor when done.
        return value;
    }
};

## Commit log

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2021-09-17 Create basic baseplate in 3d
    [BasePlate.FCStd]
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2021-09-22 Working (with one bug)
    [lab1.ino]
2021-09-24 Fix and clean lab1 demo code for full function
    [lab1.ino]
2021-09-24 Add door sensor to git
    [Door Cover.FCStd]
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2021-09-24 Layout more of the Door CAD
    [Door Cover.FCStd, Door Frame.FCStd, SensorPackage.FCStd]
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2021-09-27 Include baseline and response data from new EG207 Announcement
    [Baseline_DHT11.csv, Response_DHT11.csv]
2021-09-29 Annotations broken but we'll make do
    [__main__.py]
2021-09-29 Still todo: fix export to csv
    [__main__.py, lab1.ino]
2021-09-29 Delint, fix arduino stimulate value, more to implement tmrw
    [__main__.py, lab1.ino]
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2021-09-29 Create offical team gold response data
    [Team_Gold_Response.csv]
2021-09-29 Fix data!
    [Team_Gold_Response.csv]
2021-10-01 Fix bad csv writes
    [goldplot.py]
2021-10-01 Works but has bugs and dosent show tau
    [goldplot.py]
2021-10-01 Rearranged values for LabReport fitting
    [Team_Gold_Response.csv]
2021-10-01 Fix float translation issue
    [goldplot.py]
2021-10-01 Revert Noah
    [Team_Gold_Response.csv]
2021-10-03 midway upgrading new door assy
    [Door Cover.FCStd, Door Frame.FCStd, Sensor Mount 2.FCStd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]
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2021-10-04 Pause sensor mount here,
    [Sensor Mount.FCStd]
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2021-10-04 Add baseplate mounting holes
    [BasePlate.FCStd]
2021-10-04 Finish up last of package frame for tonight
    [BaseFrame.FCStd]
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2021-10-04 Rename Sensor Mount And remove old versions
    [Sensor Mount 2.FCStd, Sensor Mount.FCStd]
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2021-10-04 Add Drawings to sensor base plate
    [BasePlate.FCStd]
2021-10-04 Include all ignored files in gitignore
    [Door Cover.FCStd, Door Frame.FCStd, SensorPackage.FCStd]
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2021-10-04 Add resources from GrabCad
    [ArduinoMega_STEP_AP203.STEP]
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2021-10-04 Move arduino into sensor assembly
    [BasePlate.FCStd, SensorAssembly.FCStd, Standoff.FCStd]
2021-10-05 Prepare RC0 and print to find holes
    [BasePlate.FCStd, SensorAssembly.FCStd, SensorBody.FCStd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]
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2021-10-05 Add USB hole to sensor frame
    [BasePlate.FCStd, SensorAssembly.FCStd, SensorBody.FCStd]
2021-10-05 Cleanup assembly a little
    [BasePlate.FCStd, SensorAssembly.FCStd, SensorBody.FCStd]
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2021-10-08 Revert CAD History, and begin reconstruction with DHT Cutout
    [SensorBody.FCStd]
2021-10-08 Repair light sensor cutout
    [SensorBody.FCStd]
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2021-10-08 Update SensorBody to same level as previous with repaired geometry
    [SensorBody.FCStd]
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2021-10-09 Fix geometry
    [SensorAssembly.FCStd, SensorBody.FCStd]
2021-10-09 Bake ver into 3d model
    [SensorBody.FCStd]
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2021-10-19 Thread base plate standoffs
    [BasePlate.FCStd]
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2021-10-20 Bump Sensor Body Version
    [SensorBody.FCStd]
2021-10-20 Add LED status holes.
    [SensorBody.FCStd]
2021-10-20 Move LEDs to one side
    Co-Authored By: @NoahR410
    [SensorBody.FCStd]
2021-10-21 Replace lab1 tests and automated build
    [lab1.ino]
2021-10-21 Create inital CDS55 Data
    [Photoresistor_High_Response.csv, Photoresistor_Low_Response.csv]
2021-10-21 Clean High and Low response data
    [Photoresistor_High_Response.csv, Photoresistor_Low_Response.csv]
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2021-10-22 everything works except RC
    [Photoresistor_High_Response.csv, Photoresistor_Low_Response.csv]
2021-10-22 Include photoresistor Background, nominal data
    [Photoresistor_Background_Response.csv, Photoresistor_Nominal_Response.csv]
2021-10-22 Capture a photoresistor delta response.csv
    [Photoresistor_Delta_Response.csv]
2021-10-22 Get better delta response for photoresistor
    [Photoresistor_Delta_Response.csv]
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2021-10-23 Finalize CAD drawings submission
    [BasePlate.FCStd]
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2021-10-23 Fix (hopefully) sizing issue on DHT11
    Dht 11 cutout was a bit undersized, made final fit too tricky
    [SensorBody.FCStd]
2021-10-23 Fix sizing on physical status LEDs
    They needed a slightly deeper counterbore and a slightly larger dia to fit perfectly.
    [SensorBody.FCStd]
2021-10-23 I Did Nothing to it. Just saved it. :/
    [Photoresistor_Background_Response.csv]
2021-10-27 Obtain a Background Response for UV Sensor
    [UVSensor_Background_Response.csv]
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2021-10-27 Normalize all data values
    [Photoresistor_Background_Response.csv, Photoresistor_Delta_Response.csv, Photoresistor_Nominal_Response.csv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]
2021-10-28 Add hour meter hole
    [SensorBody.FCStd]
2021-10-28 Send part to printer
    [SensorBody.FCStd]
2021-10-29 Fix overlap in hour meter sketch
    [SensorBody.FCStd]
2021-10-29 correct required changes on baseplate drawing
    [BasePlate.FCStd]
2021-10-29 correct baseplate drawing date
    [BasePlate.FCStd]
2021-10-29 Lower hour meter just a tiny bit more
    [SensorBody.FCStd]
2021-10-29 Fix scale annotation on base plate
    [BasePlate.FCStd]
2021-10-31 This frame seems to fit fine
    [Door Frame.FCStd]
2021-10-31 Create matching door and cover
    [Door Cover.FCStd, Door Frame.FCStd]
2021-11-01 Add in 'fold-over' flanges and other minor improvements
    [Door Assembly.FCStd, Door Cover.FCStd, Door Frame.FCStd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]
2021-11-01 Fix parralax sizing for parralax in sensor shuttle
    [Door Assembly.FCStd, Door Cover.FCStd, Door Frame.FCStd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]
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2021-11-01 Add cutouts for CDS legs
    [Sensor Shuttle.FCStd]
2021-11-01 Add in missing lab2 schematics
    [lab2.sch]
2021-11-01 Add holes to sensor shuttle
    [Sensor Shuttle.FCStd]
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2021-11-01 Boilerplate for rain sensor housing/trap
    [Rain Flow Sensor Trap.FCStd]
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2021-11-02 Clean up shuttle base model
    [Sensor Shuttle Base.FCStd]
2021-11-03 Add nub to shuttle base
    [Sensor Shuttle Base.FCStd]
2021-11-03 Finish up for the night
    [Door Frame.FCStd]
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2021-11-04 Fix up bad dimms on door frame
    [Door Frame.FCStd]
2021-11-05 Fix, for real!
    [Door Frame.FCStd]
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2021-11-08 Fill out a lot more boilr plate, fix images in ES&I
2021-11-08 Create boilerplate Cover Drawing
    [SensorBody.FCStd]
2021-11-08 Prep for brightspace submission
    [SensorBody.FCStd]
2021-11-09 Update a few things
    [SensorBody.FCStd]
2021-11-09 Final cleanup
    Co-Authored By: NoahR410
    [SensorBody.FCStd]
2021-11-09 Bake final for brightspace
    [SensorBody.FCStd]
2021-11-10 Fix up drawing:
    [Rain Flow Sensor Trap.FCStd]
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2021-11-10 Move rain sensor into better file struct
    [Rain Flow Sensor Trap.FCStd]
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2021-11-12 Add inch annotation to baseplate drawing
    [BasePlate.FCStd]
2021-11-17 Export assy for CDR
    [SensorAssembly.FCStd]
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2021-11-17 Fix flowchart
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2021-11-17 Added Accuracies and Precisions for All Sensors
    Minor error fixed
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2021-11-17 References and Editings
    Fixed Statement Subjects, added References and in-text citations. More detail added for water level sensor.
2021-11-19 Fixup some extra bits
    [BasePlate.FCStd]
2021-11-19 Fixup counterbore detail
    [BasePlate.FCStd]
2021-11-19 This should have last of fixes
    [BasePlate.FCStd]
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2021-11-20 Flip part
    [BasePlate.FCStd]
2021-11-20 Finish flipping part
    [BasePlate.FCStd]
2021-11-20 Submit for machine shop
    [BasePlate.FCStd]
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2021-11-25 Rescale rain sensor prop for v0.1
    [Rain Flow Sensor Trap.FCStd]
2021-11-25 Create Rain Bucket Sensor Cutout
    [SensorBody.FCStd]
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2021-11-26 Fix bad drain on rain bucket
    [Rain Flow Sensor Trap.FCStd, TEST_FITTING.FCStd]
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2021-11-26 Fix tight fit on sensor package face
    [Rain Flow Sensor Trap.FCStd]
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2021-11-27 Fix a minor hose-clamp dimension bug
    [SensorBody.FCStd]
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2021-11-29 Add Sensor Limits table and blurbs for Error, warning and alarm
2021-12-03 Make light sensor servo mounting solution more robust
    [Door Frame.FCStd]
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2021-12-03 RainfallSensor table added
    Feel free to make any changes. Calculated response time.
    [RainFallSensorTable.xlsx]
2021-12-03 Fix sensor base pushbar
    [Sensor Shuttle Base.FCStd]
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2021-12-04 Fix fit in assembled frame
    [Door Frame.FCStd]
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2021-12-07 Implement error and warning clear + readout
    [cms.ino]
2021-12-07 Fix command LED
2021-12-08 Fix glitches in rainflow sensor
    [WaterLevelSensor.cpp, cms.ino]
2021-12-08 Cleanup, rename AND add door_ajar_error as error 15
    [cms.ino, constants.h]
2021-12-08 Cleanup after error 15
    [cms.ino]
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2021-12-10 prone to glitches but... error handling kinda works now
    [PlanB.py]
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2021-12-10 This is so crazy buggy omg XD
    [PlanB.py, cms.ino]
2021-12-10 Buggy af, but idk better than nothing at all
    [PlanB.py, cms.ino]
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2021-12-10 Fix bug in planb exit cleanly, fix sensor limits
    [PlanB.py, cms.ino]
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2021-12-12 Deleted TestforADP vi file and replaced it with PotentailADP VI file
    Concatenated strings used in Arduino to the device or interface specified by the VISA resource name.
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
